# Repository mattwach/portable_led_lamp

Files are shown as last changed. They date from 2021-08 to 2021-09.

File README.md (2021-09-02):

# Portable LED Lamp

*The page https://www.instructables.com/Portable-LED-Lamp and [pdf file](Portable-LED-Lamp.pdf)
contain detailed build instructions, a prebuilt firmware (`led_lamp.hex`) file
and prerendered `.stl` files.  The rest of the instructions on this page give
some additional details on the project and to explain how to build your own firmware.*

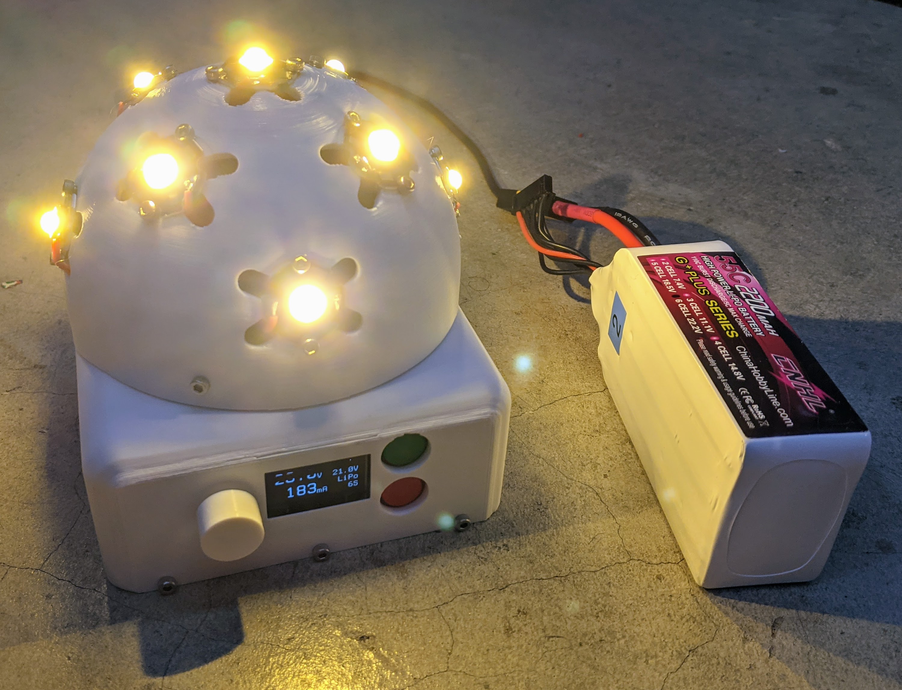
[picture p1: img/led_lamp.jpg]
Lamp Image


If you need light but don't have an outlet available, it's nice to have an
efficient light that can accept a wide variety of batteries.

This lamp can accept a wide range of voltages - between 6 and 30V. This allows
it to be **used with different batteries you may have lying around**, including
18650 packs, RC batteries, 12V lead acid, etc.

The unit is designed to be **very efficient** and puts out very little heat, even
at full power. A dimmer knob can be used to adjust the power consumption and
light output. When "off" the lamp consumes less than 40 uA of power in its
"sleep" state.

**Voltage and current are monitored on a small OLED display**. This allows you to
estimate battery life at a given light level and make adjustments as needed for
your situation.

The device has **automatic shutoff when the battery voltage gets too low**.

The device can autodetect the battery you are using with options for manual
override.

Before we get too far, a **disclaimer**:

**Using batteries carries a risk**. Making mistakes can lead to batteries catching
on fire. Sometimes batteries catch on fire even when everything is done
correctly due to unknown issues during manufacturing or shipping. It is
expected that you understand the risks associated with the battery you choose.
Even though the hardware and software in on this page have been tested, you
should not assume that your build and batteries will operate without problems.
I take no responsibility for issues you may encounter while following this
guide or using the provided software. Using a safety container for your battery
is recommended.

# Project Overview

This project contains:

  * Firmware in the `firmware/` directory.  This firmware is intended for the
    ATMega328p running at 3.3v and 8Mhz.  A 3.3V Arduino Pro Mini meets these specs
  * A [KiCad](https://www.kicad.org/) schematic and PCB layout in the
    `schematic/` directory
  * An [OpenSCAD](https://openscad.org/) 3D printable enclosure in the
    `3d_print/` directory.

# Schematics and Images

You'll want the free KiCAD tool to work on the schematics.  The images below are
screen captures from KiCAD for quick reference.

#### Master Board Schematic

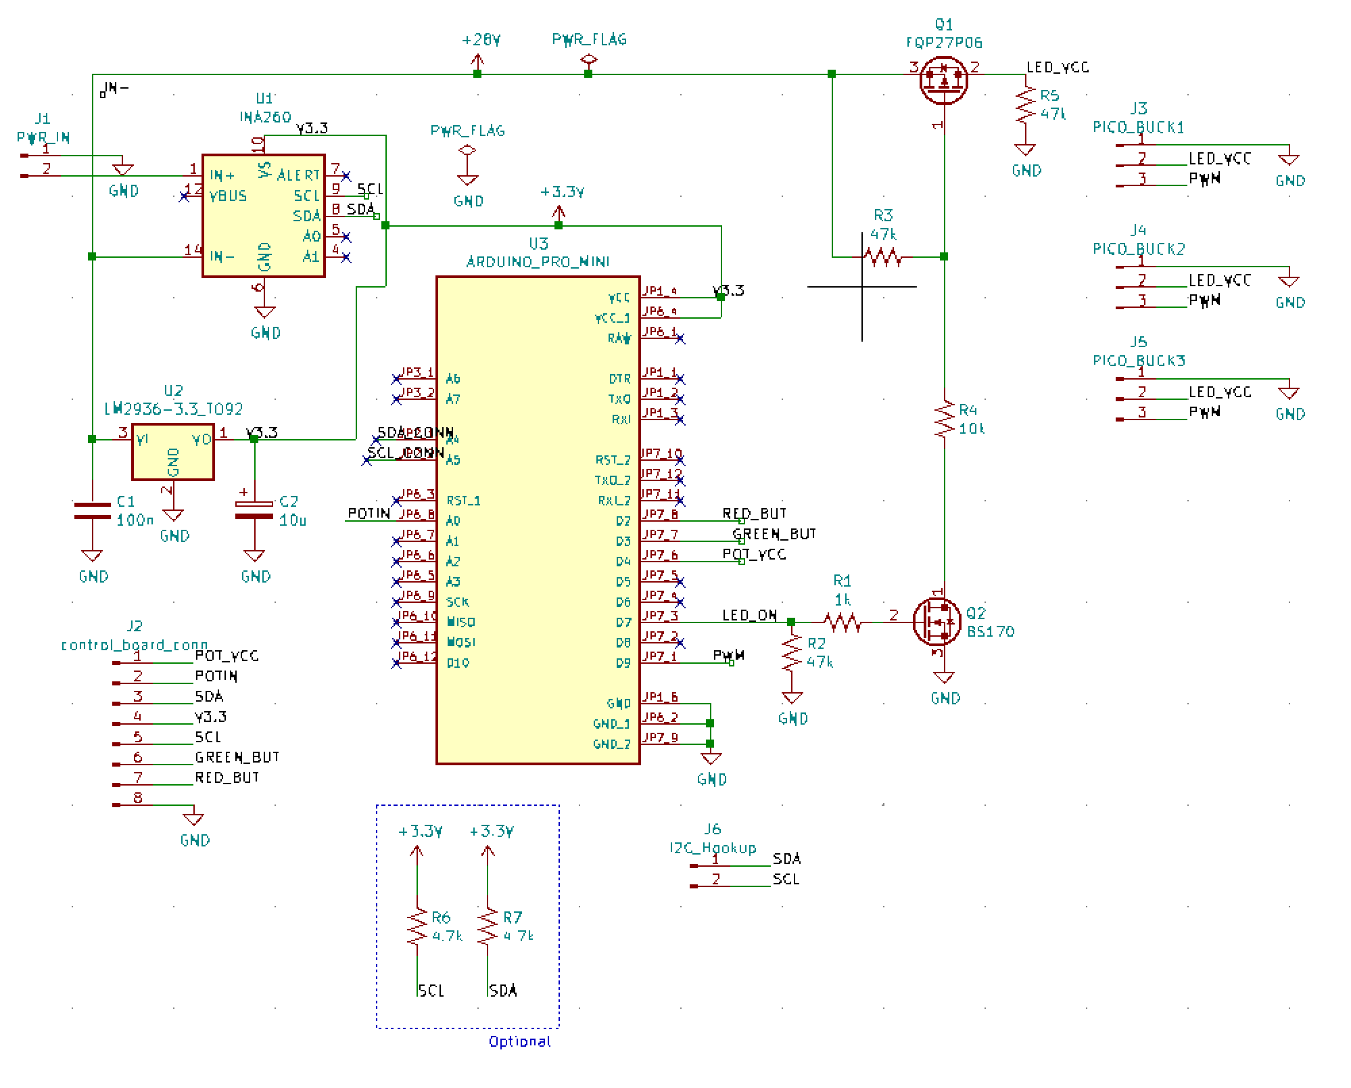
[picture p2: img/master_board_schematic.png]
Master Board Schematic


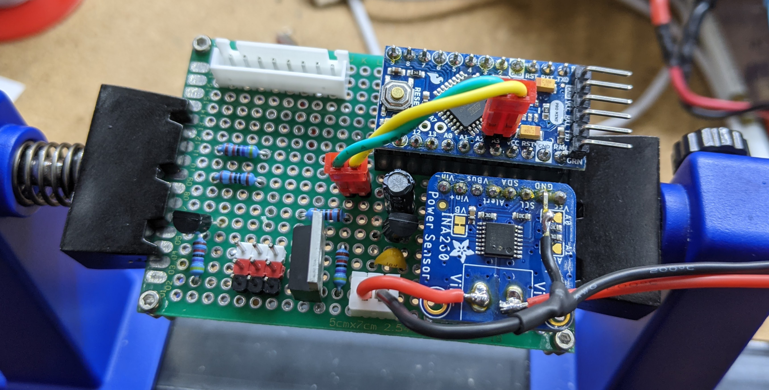
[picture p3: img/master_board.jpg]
Master Board Image


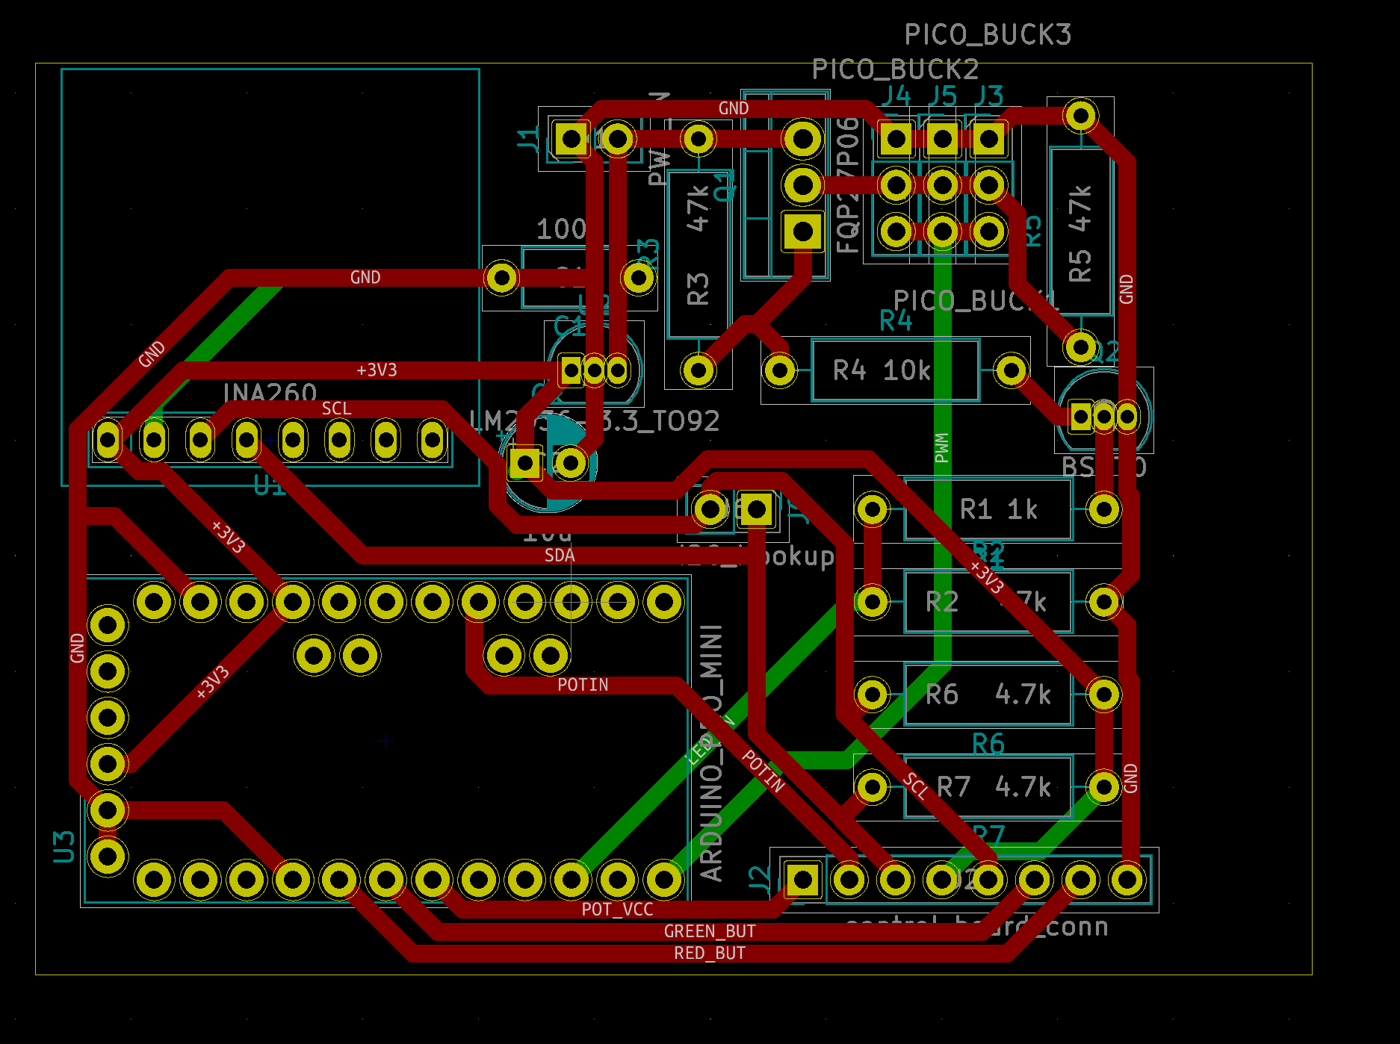
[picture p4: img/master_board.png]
Master PCB


#### Input Board Schematic

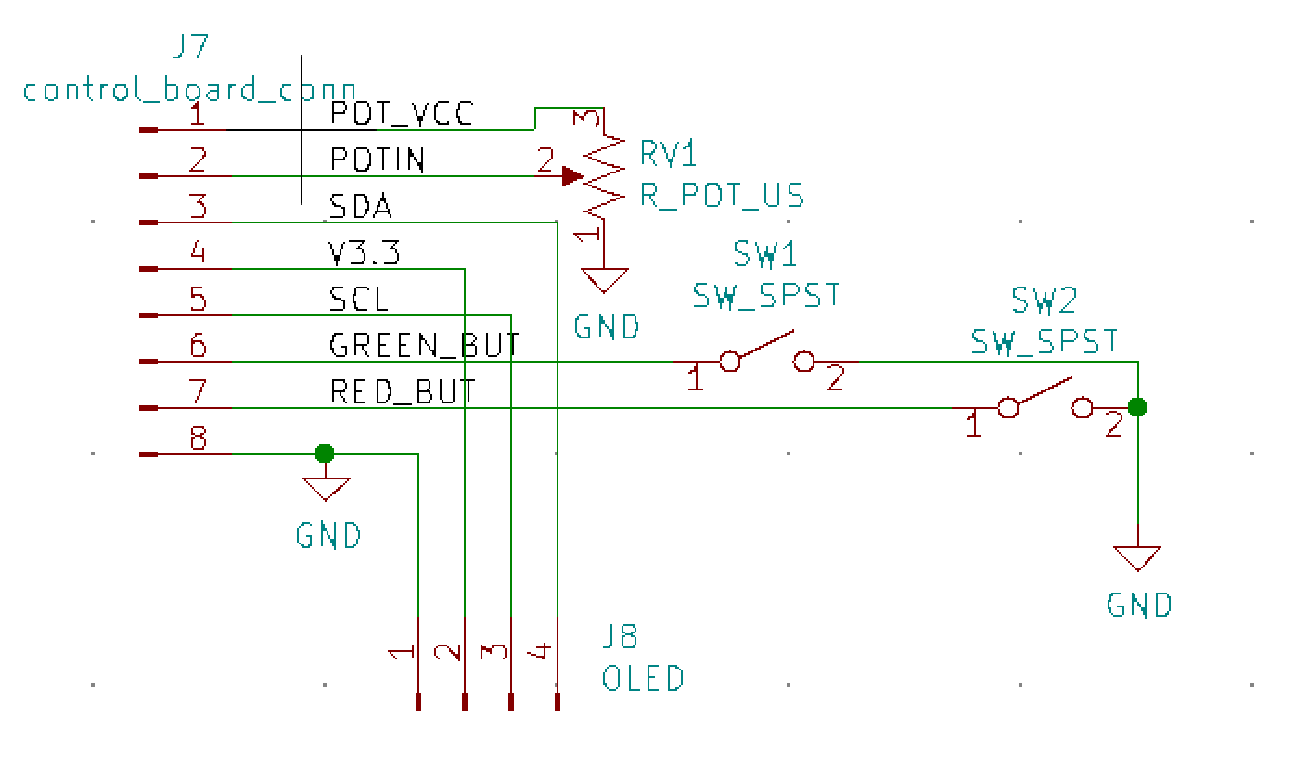
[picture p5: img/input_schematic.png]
Input Schematic


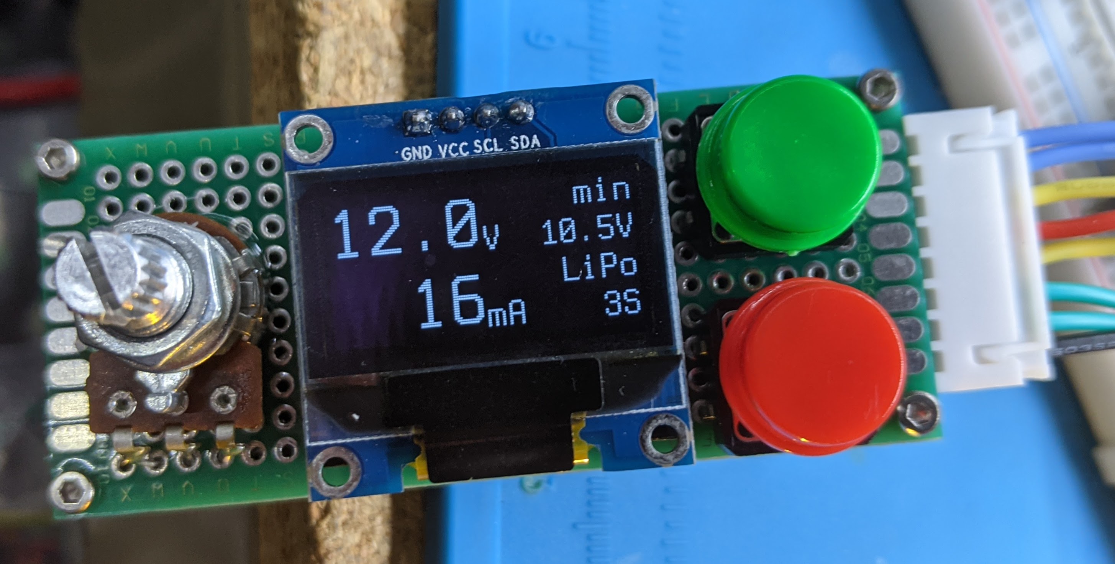
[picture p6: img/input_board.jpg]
Input Board


# Building the firmware

You will need the following commandline tools available.  All are free tools.
Getting them will vary depending on your operating system.

  * `avr-gcc`
  * `avr-objcopy`
  * `avrdude`

To build you run

    make

from the `firmware/` directory.  To upload to a ATMega328p (pro mini) you run

    make upload

Note that upload is currently not setup for windows, although it could be made
to work with a few tweaks to the relatively-simple `rules.mak` file.  The main
issue is likely to be incorrect `avrdude` parameters.  See the main `avrdude`
documentation for for more information.

# Enclosure (using OpenSCAD)

The file `3d_print/led_lamp.scad` contains the 3D models.

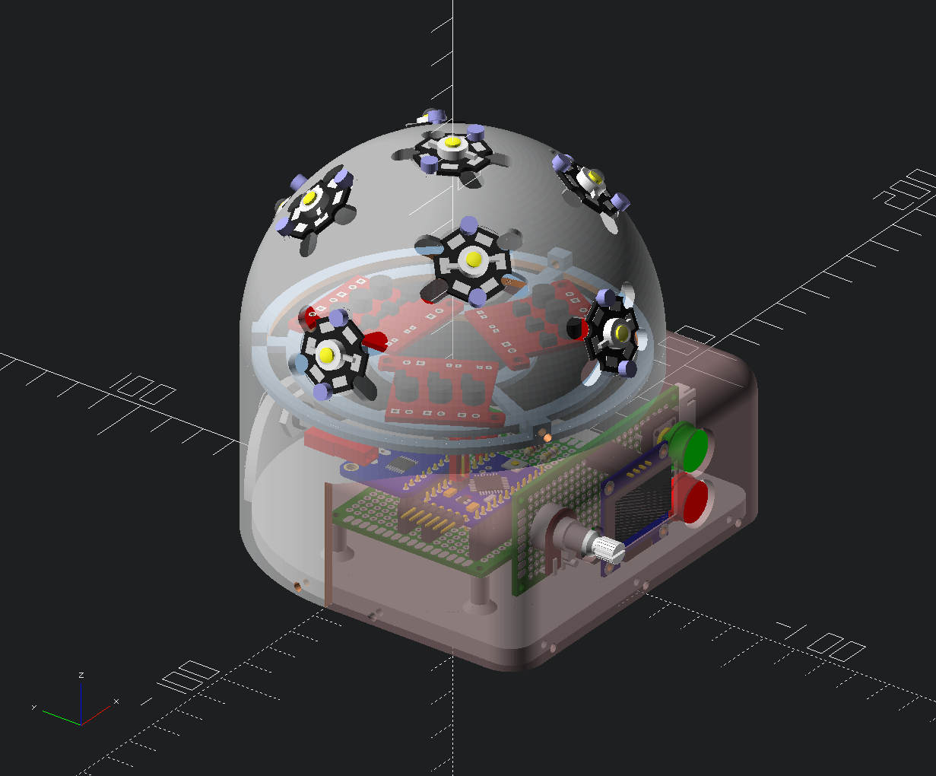
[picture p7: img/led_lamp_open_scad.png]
LED Lamp 3D Model


At the bottom of the file is a section:

    placed_master_pcb();
    placed_input_pcb();
    placed_picobuck_mount_plate(add_picobucks=true);
    placed_barrel_connector();
    lamp_base();
    placed_led_dome(show_leds=true, barrel_connector_cutout=true);
    input_holder();
    placed_dimmer_knob();

You can place a `*` character or comment out a line with a `//` to omit the
part.  You can also prefix a line with `!` to only show that part.  This is
useful for isolating a part for making a `.stl` model for printing.

# Design Notes

In have [design notes](DESIGN_NOTES.md) where I share test results for LED
efficiency, component power usage and other considerations.

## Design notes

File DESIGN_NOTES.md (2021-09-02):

# Design Notes

## Measuring LED Efficiency

The question here is what current are the LEDs the most efficient at?  Do you
get more light running 1 LED at 1W or 2 LEDs at 0.5W each?
[This website](https://tehnoblog.org/smd-led-chips-characteristics-size-power-efficiency/)
has some good information but did not cover the specific LED I purchased.  So I
decided to do some testing with a light meter.  Here is the setup:

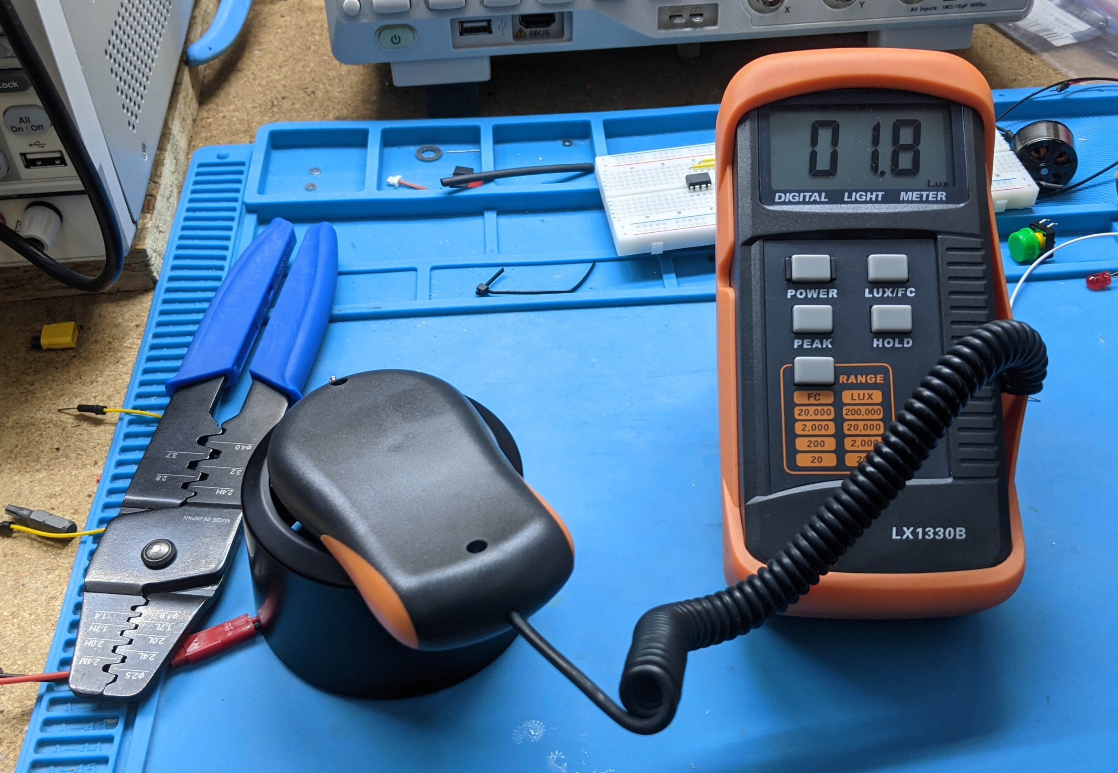
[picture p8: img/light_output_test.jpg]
Test Setup


Inside the black lens hood is an LED.  The device measures the Lux detected on
it's sensor.  I ran different currents through the LED, noting the voltage
and lux 
[recording the measurements this spreadsheet](https://docs.google.com/spreadsheets/d/1-tIt16MrtUSSaDjhF26bp0V8y1RnZGNZchjPFLyIPXU/edit?usp=sharing).
I ran 2 led's 2 times for a total of 4 measurements.  From the data, I created two graphs:

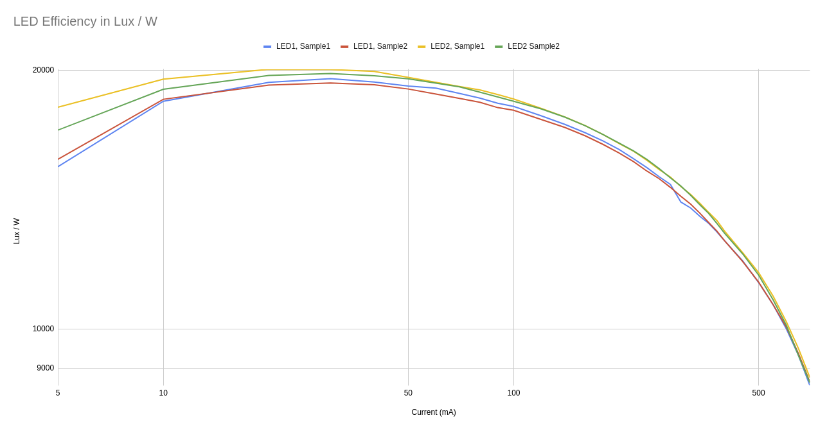
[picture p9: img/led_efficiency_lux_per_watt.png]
LED Efficiency


This graph shows Lux/Watt (efficiency) at a given current for all collected
samples.  It is showing that the LED is most efficient at ~20-50mA where
efficiency starts to drop off.  Note that the LED *is still getting brighter* as
current increases, but more energy is being *given off as heat* instead of light.
**Thus one can roughly conclude that using as many LEDs as possible is the most
efficient** as long as you are using at least 40mA per LED.

Here is another way to look at the data:

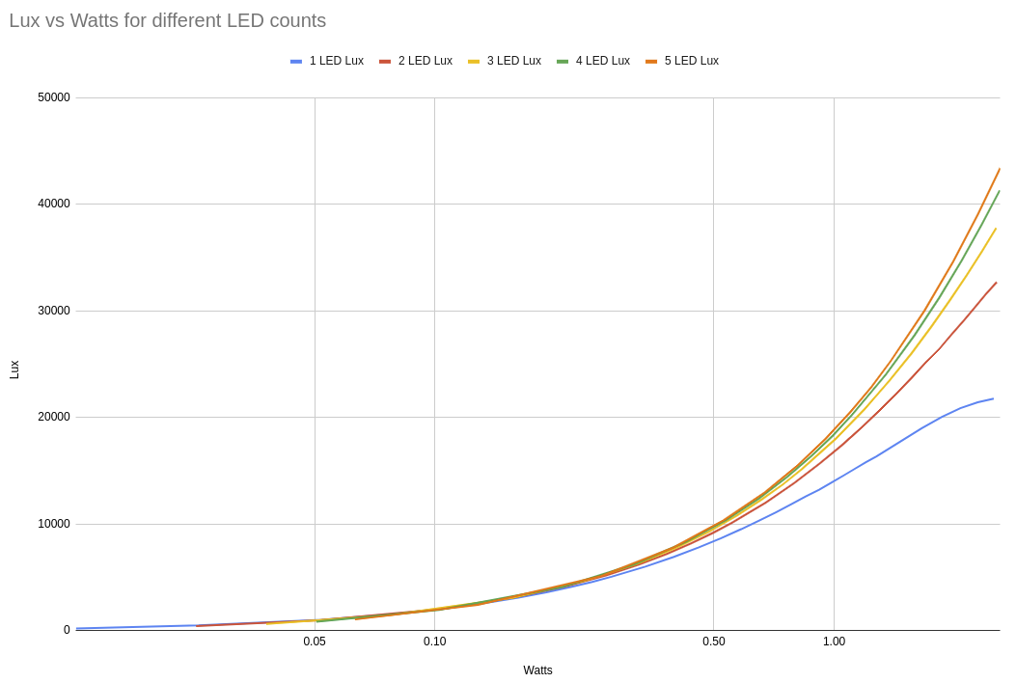
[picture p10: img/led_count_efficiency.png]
LED Count Efficiency


This case looks at choosing 1-5 LEDs and how much light you would get for a
given power budget.  From the graph, it looks like gains start around 0.5W and
become interesting above 1W.  Adding additional LED's has diminishing
returns, although still interesting at higher power budgets.

# OLED Power Consumption

To measure current, I used an ATTiny85 as the driver because it was a
convenient way to test at 3.3V (provided with a bench power supply).  Since I'm
only measuring current through the OLED, the device is irrelevant anyway.

The test toggles between the DISPLAYON and DISPLAYOFF I2C command every 4
seconds.  I wanted to see the current draw difference and get some confidence
as to the reliability of the commands (which I have not used before)

Here is the ON measurement:

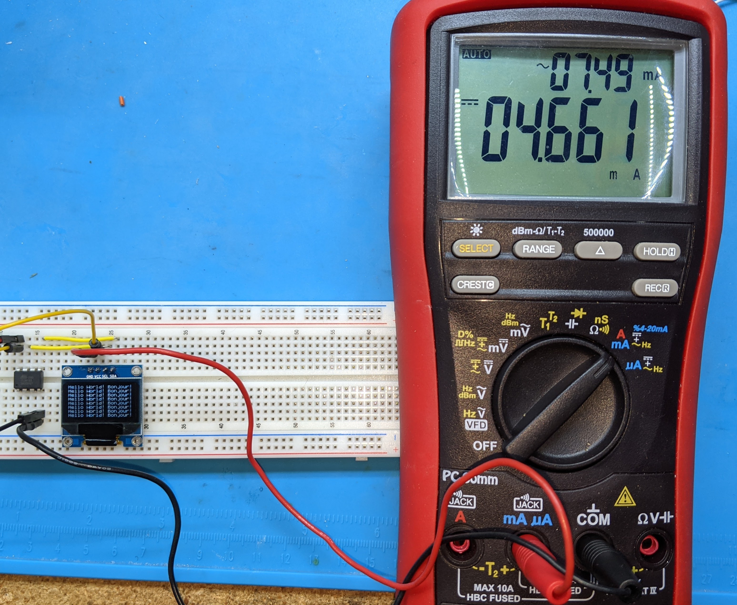
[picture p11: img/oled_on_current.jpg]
OLED On Current


4.4 mA (15 mW) is not bad but more load than I would prefer when in the
"battery is depleted" shutoff state.  4.4 mA over 24h would be 104 mAh (post
buck) which could be a problem for an already-depleted smaller 2S pack.

With the DISPLAYOFF command:

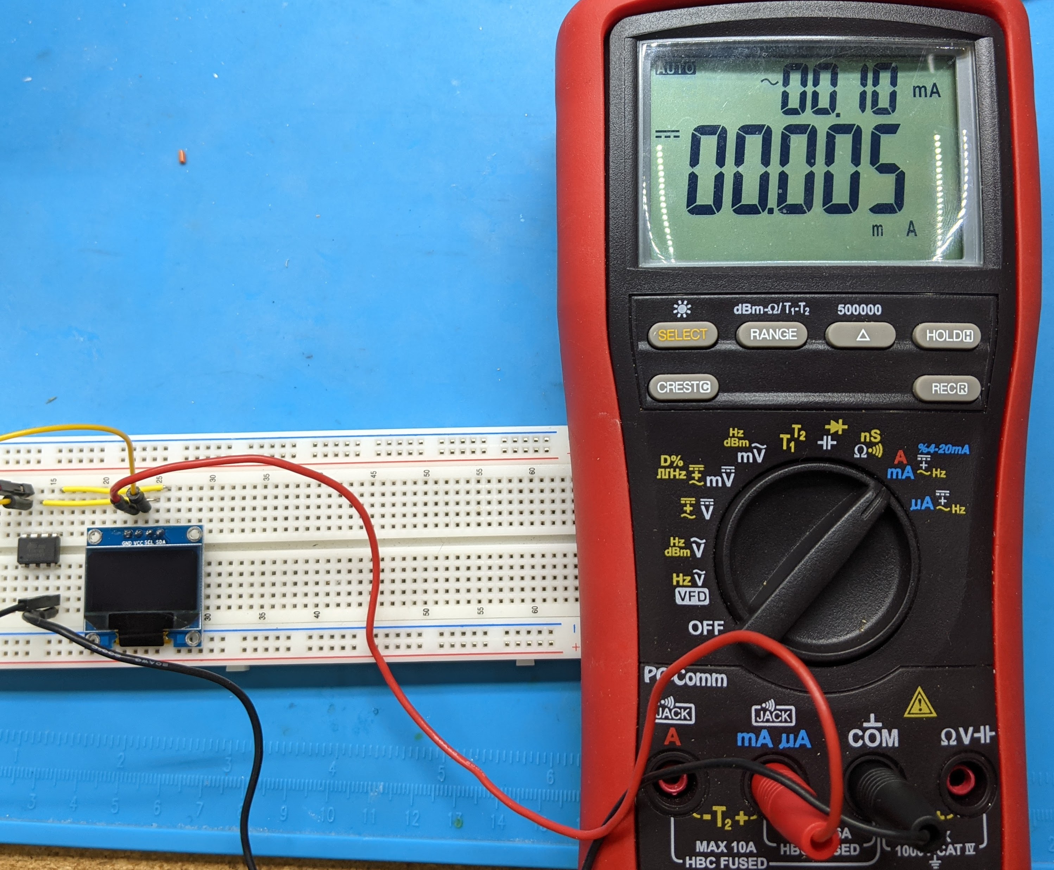
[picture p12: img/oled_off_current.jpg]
OLED Off Current


5 uA, pretty much a non-issue from the OLED, even if a small depleted pack is
left connected for a long time.

The tests also suggested that toggling between DISPLAYON and DISPLAYOFF will
work reliably.

# INA260 Testing

I setup the INA260 in an isolated test where I compared the reported value to a
multimeter measured value.  

For voltage, I found the INA260 to be very accurate.

For current, I found that the current read 2 mA low on both of my devices. By
simply adding 2mA to the result, I was able to get numbers within 1mA of the
multimeter across a 0-60mA range of values.  Good enough.

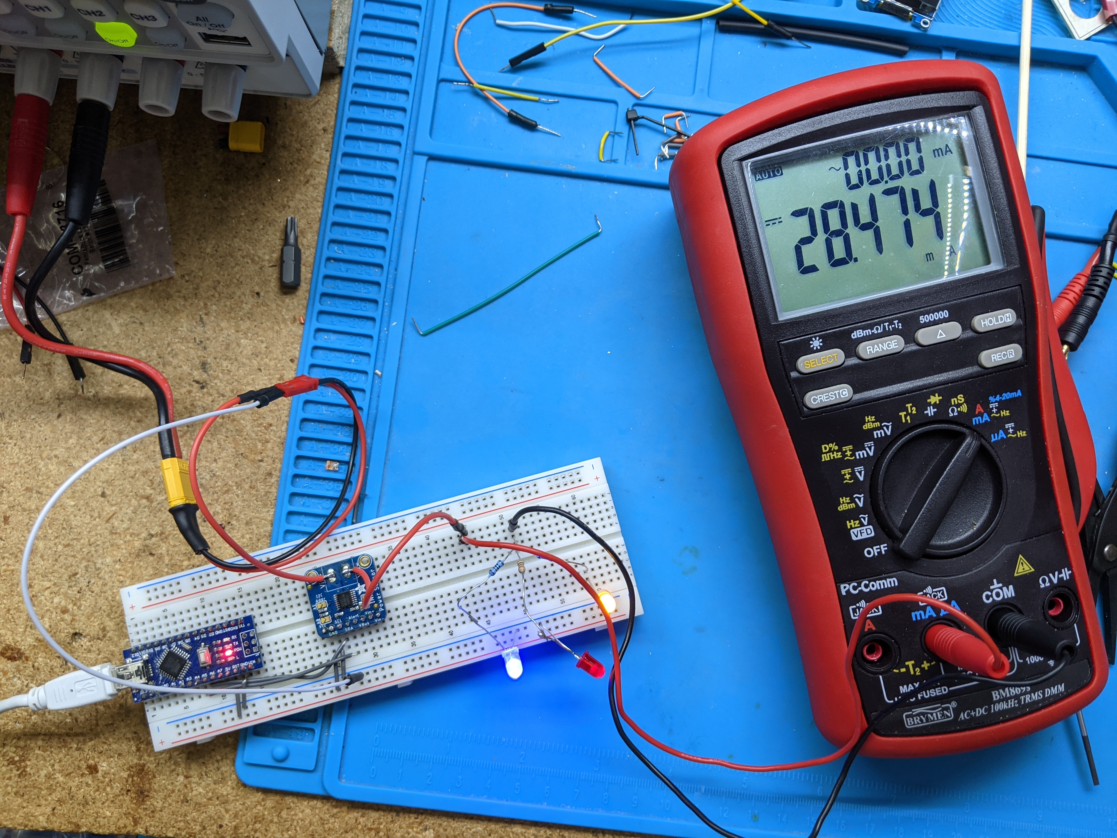
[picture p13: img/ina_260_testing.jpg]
INA260 testing


I also tested current draw into the INA260 in acive and sleep modes.  I measured
322 uA of draw in active mode and only 660 nA in sleep mode.

# PicoBuck Testing

I wanted to see if sending a grounded PWM signal to the PicoBucks would lower power
usage to acceptable levels.

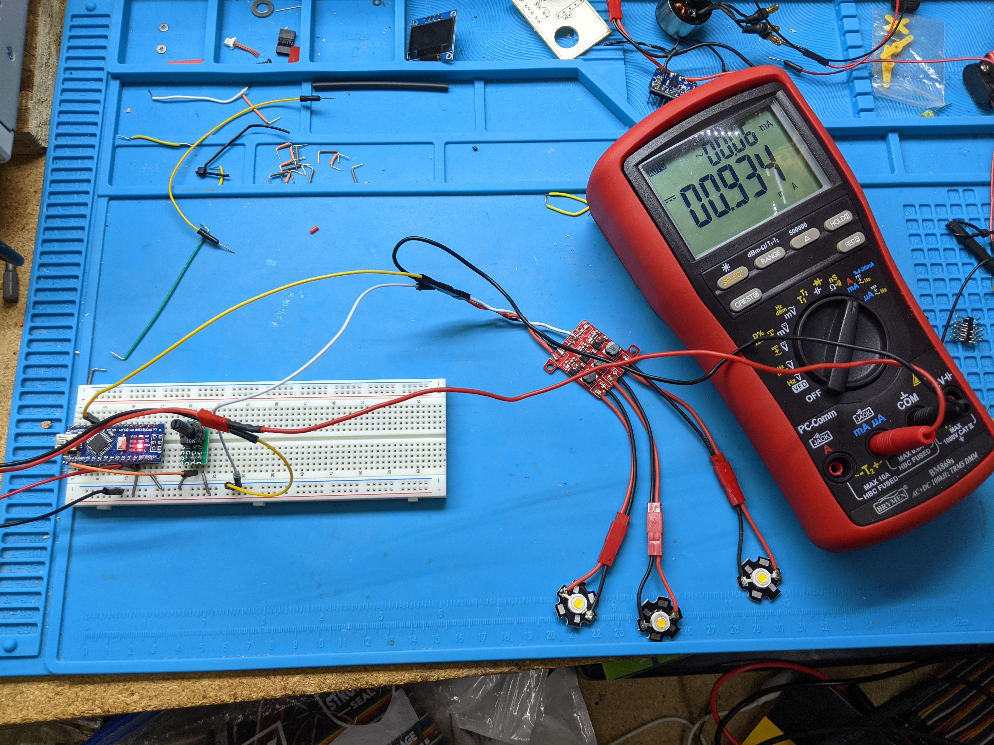
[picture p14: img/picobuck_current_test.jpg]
PicoBuck Current Test


Just a bit under 1mA.  Since I'm using 3 of these, the total "off" draw would
be just under 3 mA.  I think this is a bit too high to leave connected to a
depleted battery, thus I decided use a transistor to cut power to the PicoBucks
while the light is off.

# Pro Mini Sleep Current 

I took a current measurement of the device after removing the
built in 3.3V regulator and diode (as recommended by
[various low power guides](https://www.the-diy-life.com/making-an-ultra-low-power-arduino-pro/)),
and putting the device into low power (sleep) mode.  I measured just under 20 uA,
which is higher than the guides suggest, but low enough for my project.

# Switch Design

I decided to go with a high side PFET solution of the following design:

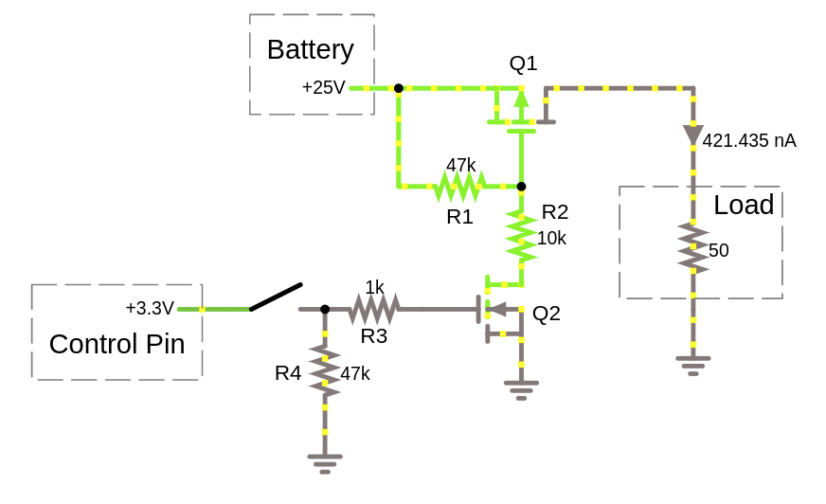
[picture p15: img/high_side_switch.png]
High Side Switch


Here are some notes on how the circuit works:

  * Q1 is the main component.  It is a Power P-Channel MOSFET.  I used the
    FQP27P06 but others could work.  As a PFET, it is "ON" when the gate voltage
    is pulled below the source.
  * R1 is a pullup resistor that turns off Q1 by default
  * R2 prevents the voltage from being pulled too low.  Every P-Channel MOSFET
    has a maximum rated Vgs that should not be exceeded and this rating will
    determine the correct ratio between R1 and R2.
  * Q2 pulls the gate of Q1 down.  Thus, when Q2 is on, Q1 is also on.  Q2 is
    needed to handle the voltage at the Q1 gate, which is too high to handle
    directly with a microcontroller.
  * R3 is used to dampen potential oscillations that can occur when switching
    Q2 on and off.
  * R4 pulls Q2 to ground by default, which means that the microcontroller does
    not need to actively drive that connection for the light to be off.  This
    provides stability while the microcontroller is starting up and is a good
    general default mode.

### N-Channel MOSFET?

Many designs go with an N-Channel MOSFET, which might require fewer components.
This "lowside" solution creates the concept of 2 independent grounds because
the PicoBuck ground would be on the high side of the MOSFET.  The PicoBuck
supports separate grounds for logic and power but now the total number of wires
to the PicoBucks is 4 (Power, Power Ground, PWM, PWM Ground) instead of 3,
something to consider if you want to modularize the design.

A bigger issue is that 3.3V doesn't fully saturate most N-Channel MOSFETs, which
will limit the current to some peak value that varies by MOSFET.  To Overcome
this, we would either need to switch to 5V logic (which uses more power), or
add an additional transistor to allow a higher Vgs (which negates the
simplicity).

### Darlington NPN?

This low side solution should work fine and would be a fairly simple circuit.
There will be a bit of power lost at the Vbe junction and current limiting
resistor when the circuit is on but it could be argued as acceptable.  A
reasonable alternative with the same "2 grounds" downside as the N-Channel
MOSFET.

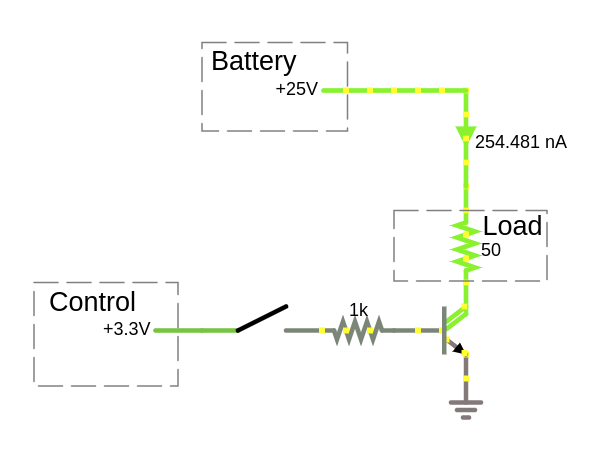
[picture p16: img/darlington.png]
Darlington Low Side


### Relay?

The main benefit of a relay is *potential* full isolation between logic and
power.  This is not needed or usable here, since the same battery powers the
logic and LEDs.  Downsides differ between mechanical and solid state.  For
mechanical, managing the coil is a downside.  Solid state could be fine but
check the datasheet specifications.

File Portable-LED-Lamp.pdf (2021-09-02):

instructables

Portable LED Lamp (http://www.instructables.com/Portable-LED-Lamp/)

by mattwach (http://www.instructables.com/member/mattwach/)

Note: this page focuses on building the lamp. If you want to customize the rmware, hack on the 3D models, or read about more design details,see the associated github project. (https://github.com/mattwach/portable_led_lamp)
If you need light but don't have an outlet available, it's nice to have an ecient light that can accept a wide variety of batteries.
The lamp can accept a wide range of voltages - between 6 and 30V. This allows it to be used with di

erent batteries
you may have lying around, including 18650 packs, RC batteries, 12V lead acid, etc.
The lamp is designed to be very ecient and puts out very little heat, even at full power. A dimmer knob can be used to adjust the power consumption and light output. When "o-" the lamp consumes less than 40 uA of power in its "sleep" state.
Voltage and current are monitored on a small OLED display. This allows you to estimate battery life at a given light level and make adjustments as needed for your situation.
The device has automatic shuto

when the battery voltage gets too low. The device can autodetect the battery you are using with options for manual override.
Before we get too far, a disclaimer:
Using batteries carries a risk. Making mistakes can lead to batteries catching on re. Sometimes batteries catch on re even when everything is done correctly due to unknown issues during manufacturing orshipping. It is expected that you understand the risks associated with the battery you choose. Even though the hardware and software in on this page have been tested, you should not assume that your build and batteries will operate without problems. Itake no responsibility for issues you may encounter while following this guide or using the provided software. Using a safety container (https://www.amazon.com/Lipo-Storage/s?k=Lipo+Storage) for your battery is recommended.

Supplies:
Needed Supplies
This is what I used. If you understand the design, you can swap out many of the parts below for alternatives.
1. 3.3V Arduino pro mini: (https://www.sparkfun.com/products/11114) $10 (or a low cost clone (https://www.ebay.com/itm/333324921249) $3)
2. 3 PicoBuck LED drivers: (https://www.sparkfun.com/products/13705) $48
3. 10 3W leds (solds in packs of 5): (https://www.sparkfun.com/products/13104) $16 (or cheaper ones on ebay (https://www.ebay.com/itm/122604065816) $5)
4. 128x64 I2C OLED (US shipping): (https://www.ebay.com/itm/382850692423) $6 (or CN shipping (https://www.ebay.com/itm/313626641218) $2)
5. 3.3V Regulator LM2936: (https://www.digikey.com/en/products/detail/texas-instruments/LM2936Z-3.3-NOPB/440974) $2
6. INA260 Voltage/Current monitor: (https://www.adafruit.com/product/4226) $10
7. 10k rotary potentiometer: (https://www.sparkfun.com/products/9939) $1
8. 2x tactile buttons: (https://www.sparkfun.com/products/15326) $1
9. 5.5mm jack for power: (https://www.amazon.com/ThreeBulls-Pieces-5-5mmx2-1mm-Female-Connector/dp/B01N8VV78D) $2
10. P-Channel power MOSFET. (https://www.sparkfun.com/products/10349) I used the FQP27P06 (https://www.sparkfun.com/products/10349) but many could work. It just has to have a Vdss > 30V
Portable LED Lamp: Page 1

and an Id > 2A ($1)
11. N-Channel MOSFET. (https://www.digikey.com/en/products/detail/onsemi/BS170/244280) I used the BS170 (https://www.digikey.com/en/products/detail/onsemi/BS170/244280) most but anything with a Vdss >30V will work. (< $1)
12. Resistors: I used 3x 47k, 1x 10k and 1x 1k. Most of these values are not critical, ballpark will do. The one exception is the 1:5 ratio between the 47k and 10k should be similar.
13. PCB boards. I used a 30x70 and 50x70 prototype board (https://www.amazon.com/ELEGOO-Prototype-Soldering-Compatible-Arduino/dp/B072Z7Y19F). If you want to send the design to a fab, see the github ?les. (https://github.com/mattwach/portable_led_lamp)
14. M2 (https://www.amazon.com/Hilitchi-250-Piece-Stainless-Socket-Assortment/dp/B01N1WDUK0) and M2.5 (https://www.amazon.com/DYWISHKEY-Pieces-Stainless-Socket-Washers/dp/B082XPZV1V) bolts if you choose to use the 3D printed housing.
15. Some hookup wire. I think 22 gauge silicone wire (https://www.amazon.com/BNTECHGO-Flexible-Conductor-Resistant-Extension/dp/B077XBWX8V) is a good ?t but you can use what you have.
16. Optional: Connector between input PCB and main PCB. I went with 8 pin JST XH (https://www.amazon.com/Connector-pre-crimped-Housing-Adapter-Compatible/dp/B08G18PWQ6) connectors but many di-erent options can be used.
17. Optional: Some female pin headers (https://www.amazon.com/Glarks-Straight-Connector-Assortment-Prototype/dp/B076GZXW3Z) will allow you to plug and unplug the OLED, Power Monitor and Arduino. This can help with troubleshooting and protects the parts when soldering.

Price Range: $60 - $150, depending on where you get components, optional parts, shipping, etc.
Needed Tools
1. A 3.3VFTDI programmer. (https://www.sparkfun.com/products/9873) The linked one is $15 but there are many cheap alternatives.
2. A soldering iron and solder
3. Hex wrenches for assembly.
4. Optional: an ESD wrist strap (https://www.amazon.com/Corpco-Anti-Static-wrist-strap-removable/dp/B01D0O7M4E) is recommended when handling the MOSFETs. (https://e2e.ti.com/blogs_/b/powerhouse/posts/what-type-of-esd-protection-does-your-mosfet-include)
5. Optional: a breadboard will be useful for incremental validation.

This project also includes .stl ?les for a 3D printed enclosure. You can print it yourself, send the ?les to a service, or DIY your own case solution.
Needed Software
1. AVRDude (https://www.nongnu.org/avrdude/) for uploading ?rmware to the pro mini (free).
2. Optional: AVR GCC tools (https://www.google.com/search?q=avr+gcc+compiler) if you want to hack on the ?rmware or write your own. (free)
3. Optional: OpenSCAD (https://openscad.org/) if you want to hack on the 3D model ?les. (free)

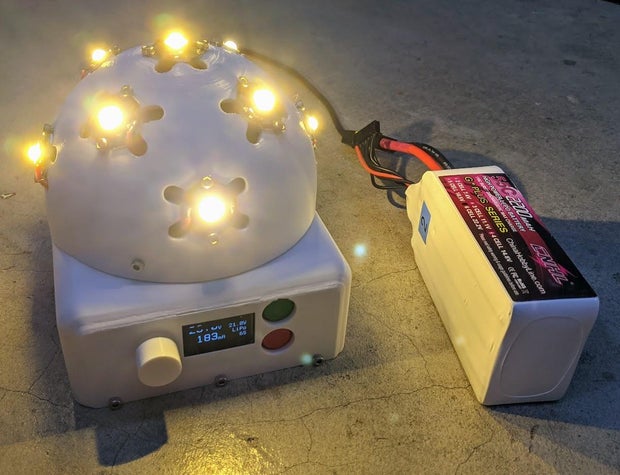
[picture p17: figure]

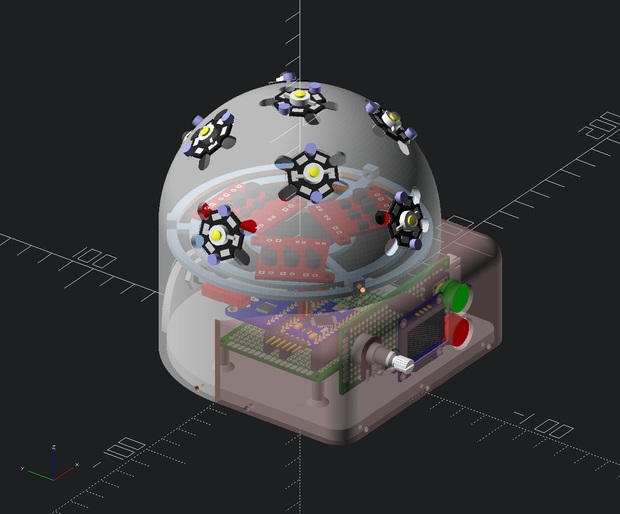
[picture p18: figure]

Step 1: Main Schematic Overview

Let's start with an overview of where we are headed. The schematic shows the ?nal circuit with everything connected. If this information looks overwhelming, feel free to skip it as we will be walking through the design in the upcoming steps:
Power comes in at the top left on J1, Pin 2. It feeds directly into the V+ port of an INA260 power meter. The power Iows through the V- port of the INA260. The INA260 will measure current that passes through V+ and V- and the voltage between V+ and GND
The V- of the INA260 connects to 2 devices
One is the LM2936 voltage regulator on the left (U2). This regulator drops the voltage down to 3.3V which is needed by the Arduino pro mini, the INA260 and the OLED. Although the pro mini has a built in 3.3V regulator, this built in regulator can not handle the 30V maximum rating on V-. The pro mini regulator also has a higher "quiescent current" which means that it is less power-ecient than the LM2936.
The other device connected to V- is a PFET (Q1). This is used to cut power to all to the

PicoBuck LED drivers. The 47k pull resistor (R3) pulls the gate to V- by default meaning that the PFET is o- by default.
The resistors and Q2 (NFET) are needed to switch the PFET on. The pro mini can not turn on the PFET directly because the voltage at the PFET gate is too high, thus an NFET (Q2) is used as a middle-man. The resistors R3 and R4 are used to keep the Vgs speci?cation of the PFET in range. The R2 resistor keeps Q2 o- by default. To turn on Q2, the arduino pro mini must drive D7 high. The R1 resistor consumes potential oscillations that can develop when switching Q2 on and o-.

Back to Q1, the PFET either blocks (nearly all) current or allows (nearly all) current, depending on it's state. The receivers of this current are 3 PicoBuck LED drivers, which are used to drive 9 3W LEDs.
Let's focus on the pro mini's interface pins
A4 (SDA), A5 (SCL): These are used to talk to both the INA260 and OLED via I2C. I2C is a bus architecture meaning that A4 connects to SDA of both the INA260 and OLED at the same time. Same for SCL.
A0: This connects to the center leg of a potentiometer for dimming the LEDs.
D4: This connects to the voltage (right) leg of the potentiometer. You could hook this leg directly to the 3.3V supply, but then the potentiometer would burn power even when the light is o-. By using D4, the pro mini can cut the power to the potentiometer when the unit is o-, saving 330 uA of current draw.
D2: This connects to the "green" push button. The other side of the button is connected to GND. This con?guration is called "open drain". Basically a pullup resistor internal to the pro mini keeps D2 high at 3.3V but this voltage can easily be pulled to ground by something like a button - which the pro mini will detect as a button press.
D3: Same idea as D2 but for the red button
D7: The arduino drives this pin to 3.3V to turn on Q2, which in turn turns on Q1, which turns on the LEDs. To turn o- Q2, we have the choice or driving D7 to GND or re-con?guring it as an input (Hi-Z) and letting R2 pull the gate to ground. The ?rmware takes the later choice. D9: This pins sends out a PWM signal. It tells the PicoBucks how much to dim the LEDs. The ?rmware makes this decision by considering the state of the lamp (is it on? is the voltage ok?) and by reading the potentiometer value
3.3V VCC, GND: Needed to power the chip

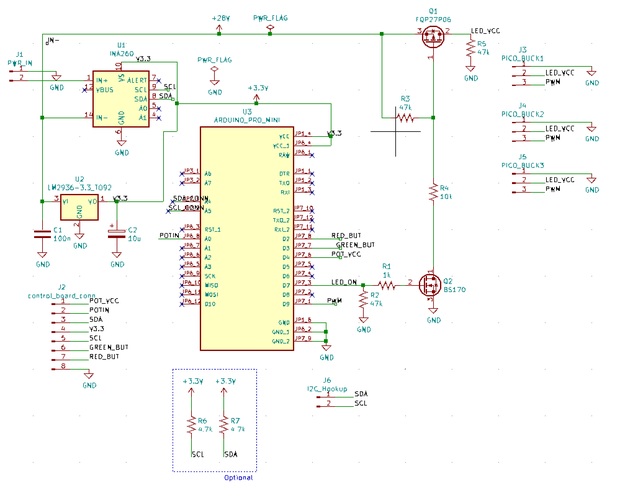
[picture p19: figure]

Step 2: Input Schematic Overview

The input PCB is wired on a separate board and connected via an interface cable to the main board. You don't have to use an interface cable if you are making your own case and want everything on one board.
Every component on this board was described in the previous step. If it's not clear what is going on, the upcoming breadboard examples should help.

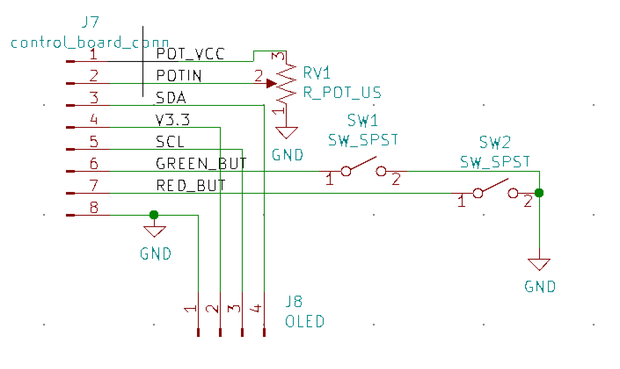
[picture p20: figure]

Step 3: Initial OLED Hookup and Firmware Test

Note: Consider all of the breadboard steps optional exercise for fun, education and part veriDcation. If you want to skip ahead to the Dnal build, feel free (and good luck).
For this step, we are just going connect the Arduino Pro mini to the OLED and upload ?rmware to the pro mini.
I recommend using a breadboard for this step.
1. Add the pro mini and OLED to the breadboard
2. The wiring to the OLED is
1. Pro Mini GND → OLED GND
2. Pro Mini VCC → OLED VCC
3. Pro Mini A4 → OLED SDA
4. Pro Mini A5 → OLED SCL
3. Now attach your 3.3V FTDI programmer to the Arduino Pro Mini Interface pins as shown in the photo and connect the USB cable to your PC

Now you need to upload the led_lamp.hex ?rmware ?le (link is below). This requires avrdude to be installed on your computer.
The command I used was:

<strong>avrdude -Cavrdude.txt -v -patmega328p -carduino -P/dev/ttyUSB0 -b57600 -D -Uflash:w:led_lamp.hex:i</strong>

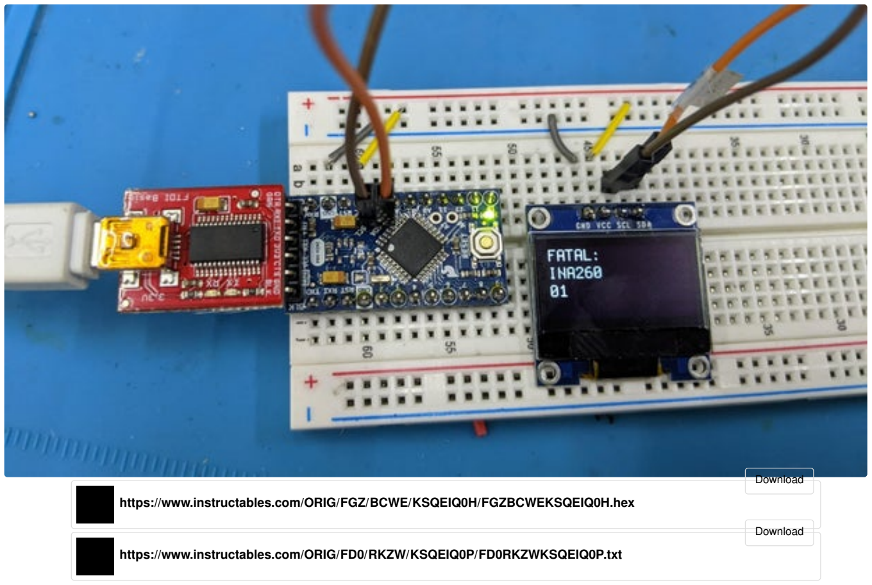
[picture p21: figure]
https://www.instructables.com/ORIG/FGZ/BCWE/KSQEIQ0H/FGZBCWEKSQEIQ0H.hex; Download; https://www.instructables.com/ORIG/FD0/RKZW/KSQEIQ0P/FD0RKZWKSQEIQ0P.txt

Step 4: INA260 Current Monitor Setup

I tested this in Arch Linux and Debian Linux but avrdude works on Mac and Windows too - you will need to adjust (or omit) the -P setting to correctly point to your serial device. Here are some avrdude docs (https://www.ladyada.net/learn/avr/avrdude.html) that might help with windows or mac.
You should see the error "FATAL: INA260 01". Although an error is being reported,things are going wellif you see this message (as we have not added the INA260 yet).

The INA260 current monitor is used to measure the voltage and current of the LED.
For now, we can just connect it onto the breadboard (the red wires in the photo are not connected to anything)
1. Connect Pro Mini GND → INA260 GND
2. Connect Pro Mini VCC → INA260 VCC
3. Connect Pro Mini A4 (SDA) → INA260 SDA
4. Connect Pro Mini A5 (SCL) → INA260 SDL

You will notice that all of the connections above are also connected to the OLED which is ?ne.
Power up the unit again and you should see it asking what type of battery you have as well as telling you you have zero volts.

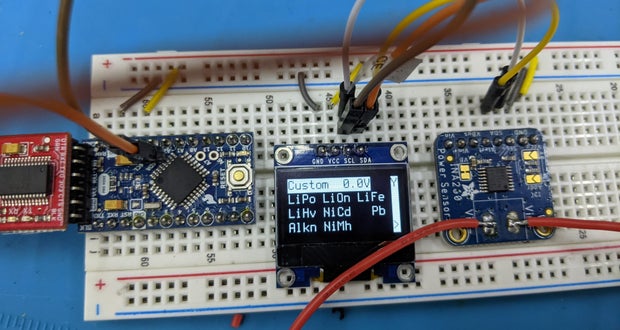
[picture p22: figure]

Step 5: Adding the Voltage Regulator

So far, the 3.3V has been provided by the FTDI programming board. For this step, we will install the voltage regulator so that we can run o- arbitrary (e.g. 6-30V) input power. That allows us to see the INA260 working now and allows us to power real LEDs later.
Wiring errors here can burn up parts. One way to avoid this it to use a regulated power supply and set the maximum current low (20 mA should be enough for now). Another way is to put a small fuse in series with your battery. A third way is to verify that the 3.3V regulator is working as expected before connecting anything to it.
The basic wiring Iow is as follows:
1. Battery + → V+ on the INA260
2. Battery - → GND
3. INA260 V- → Regulator Vin
4. Regulator Vout → 3.3V rail (which the pro mini, OLED and INA260 are all connected to)
5. Regulator GND → GND
6. Put the capacitors on the regulator as described by the datasheet.
1. The LM2936 datasheet (https://www.ti.com/lit/ds/symlink/lm2936.pdf) calls for Vin → 100nF → GND and Vout → 10uF → GND
2. . I have con?rmed with an oscilloscope that not using caps as suggested leads to unstable regulation with this part.

Your reward for getting everything correct is that the ?rmware will now show your voltage on startup. We still have no way to communicate with the unit but that will soon change.

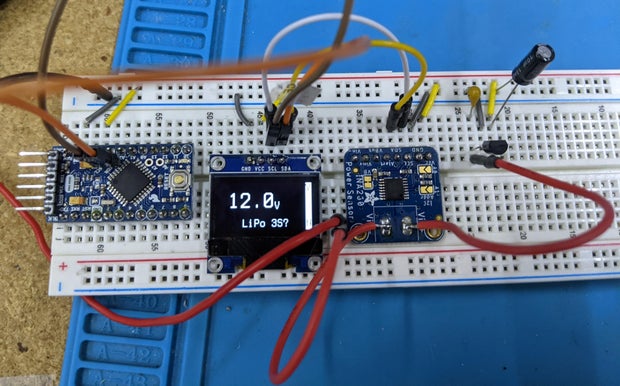
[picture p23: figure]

Step 6: Add Buttons and the Potentiometer

Here we add buttons and the potentiometer to the breadboard. In the next step, we build an input board. If you don't have good components for the breadboard, you can skip to the next step.
The buttons and potentiometer I used in this step are not the ones I'm using in the ?nal design, just some from the parts box. Wiring is as follows:
Pro Mini D2 → Red button (left side) Red button (right side) → GND
Pro Mini D3 → Green button (left side) Green button (right side) → GND Potentiometer (left pin) → GND
Pro Mini A0 → Potentiometer (center pin) Pro Mini D4 → Potentiometer (right pin)

Now you can control the unit. The unit will think it's controlling a real LED at this point and the controls will respond like the ?nal design. In this design green is on, red is o- and the potentiometer controls brightness.
Here I added a temporary LED and resistor (1k) between D9 and GND. D9 is the PWM output that will allow us to dim our LEDs. In the ?nal design, D9 is just a signal to the Picobuck converters but here I use it to drive power through a small led for a direct demonstration. The oscilliscope signal shows the output of D9. As you turn the potentiometer to the right, the duty cycle of the square wave changes and is at 3.3V for more of each period. The buttons also change the state of the unit and turns the PWM on and o-.

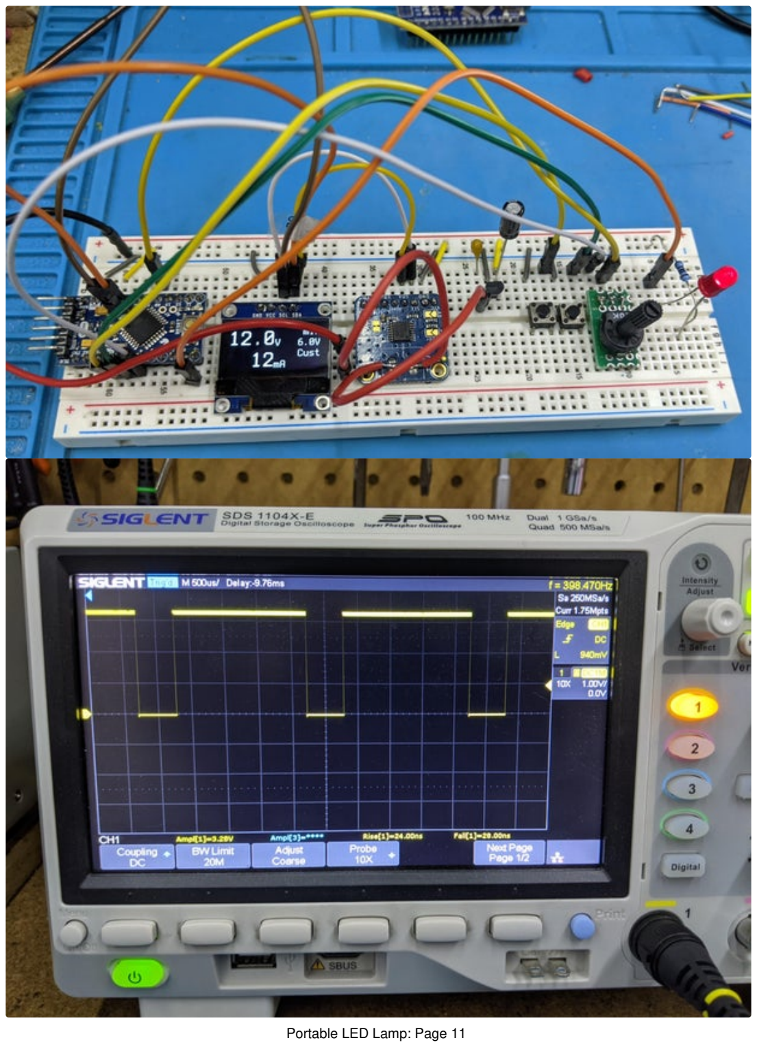
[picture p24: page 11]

Step 7: Build the Input Board

See the schematic in step 2 for the wiring. I used a 70x30mm prototype PCB for this. If you want the input board to ?t nicely into the 3D print, pay close attention to the part placement. I suggest counting the PCB holes as a reference.
I glued the potentiometer to the board with epoxy.
To connect the input board to the main board (and breadboard), I went with a male 8 pin JST XH connector (2.54 mm pin pitch). You can go with whatever connector you want, including directly soldering on the wires.

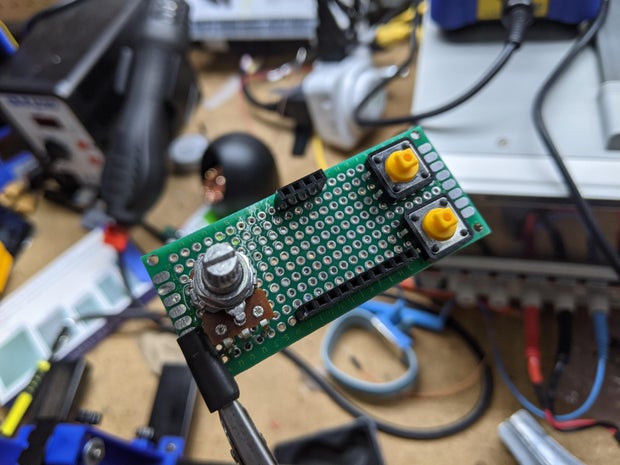
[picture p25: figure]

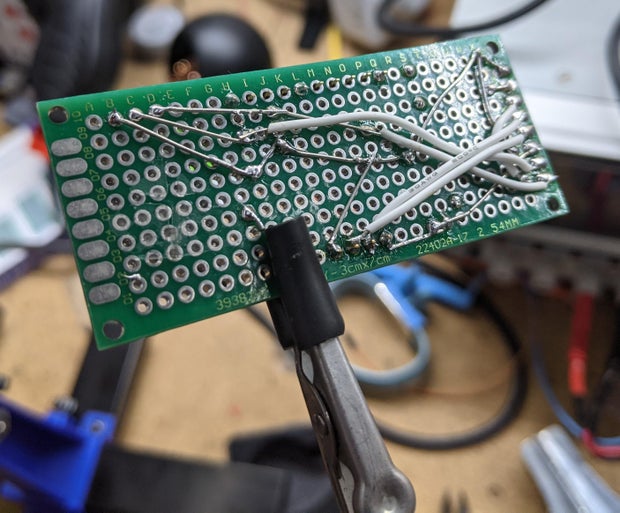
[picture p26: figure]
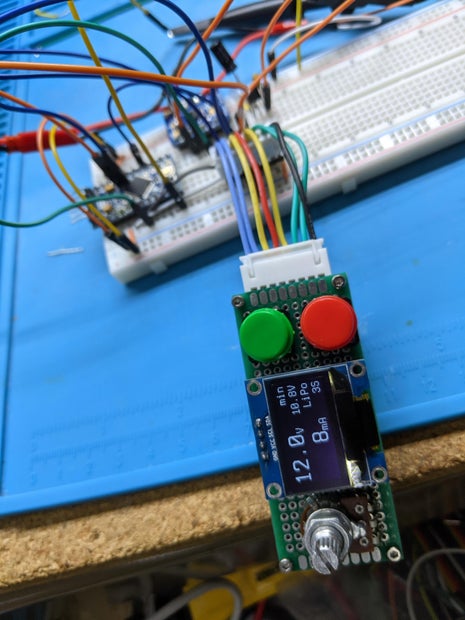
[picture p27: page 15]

Step 8: Prepare a PicoBuck and 3 LEDs

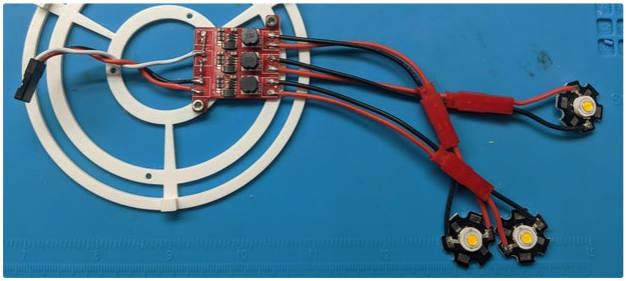
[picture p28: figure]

Step 9: Wire Up and Test the PFET Switch

The photo shows the PicoBuck on the 3D printed assembly but you do not need the assembly yet.
For the PicoBuck, you can short all of the PWM inputs together as shown in the photo. You can also short together the signal and LED GND on the board (assuming you go with the high-side PFET switch used in this guide. If you opt for a "low side" switch, you would not short them).
I used JST connections between the LEDs and picobuck. It's probably not necessary. As long as your wires are 3.5-4 inches (90-100mm), you should be able to use the 3D printed dome without the connectors.

The schematic is in step 1. You basically need a power PFET, any NFET and 4 resistors. The 47k pulldown from the PFET to the PicoBuck is optional - it will allow the voltage to drop to zero when the PFET is o-.
The photo shows a FemToBuck instead of a PicoBuck. They can be used interchangeably.
Note: you also have the option of omitting the PFET/NFET switch, plugging V- from the INA260 directly into the PicoBuck power input. Things will still work as the "o-" position of the ?rmware also Iatlines the PWM signal at D9. The downside is that each PicoBuck uses about 1 mA in this con?guration for a total waste of 3mA, even when the unit appears o-. Using the PFET avoids this 3 mA parasitic drain.

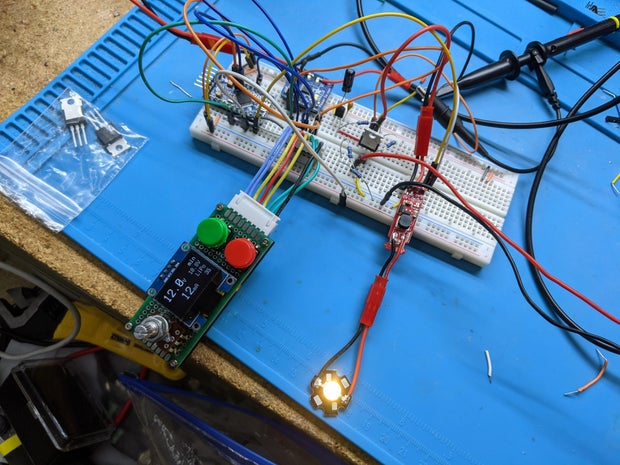
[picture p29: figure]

Step 10: Build Master PCB

Now we transfer the breadboard circuit to a PCB. I used a 50x70mm PCB which is also what the 3D print is designed to use. I used kicad (https://www.kicad.org/) to help layout the components (?les here) (https://github.com/mattwach/portable_led_lamp) before wiring up the board. Note that the kicad schematic contains 4.7k pullup resistors for SDA and SCL. The INA260 and OLED already have pullup resistors onboard and the 4.7k pullups were never needed in testing, so I did not include them in my actual wiring.

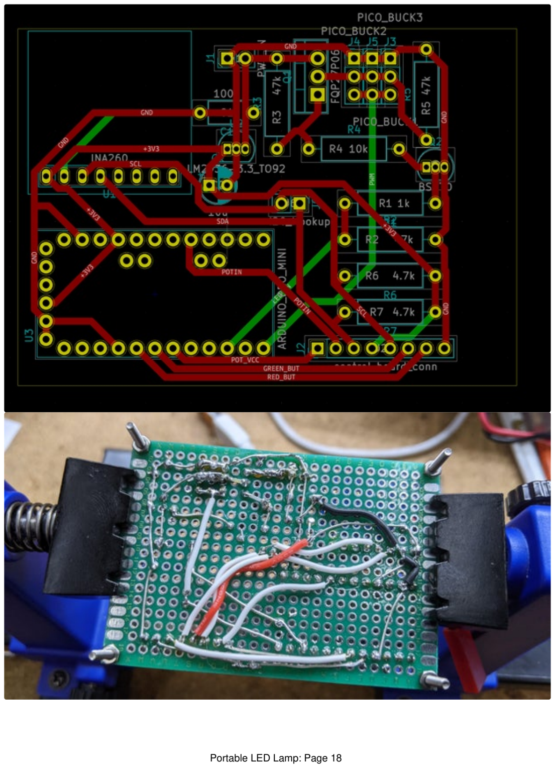
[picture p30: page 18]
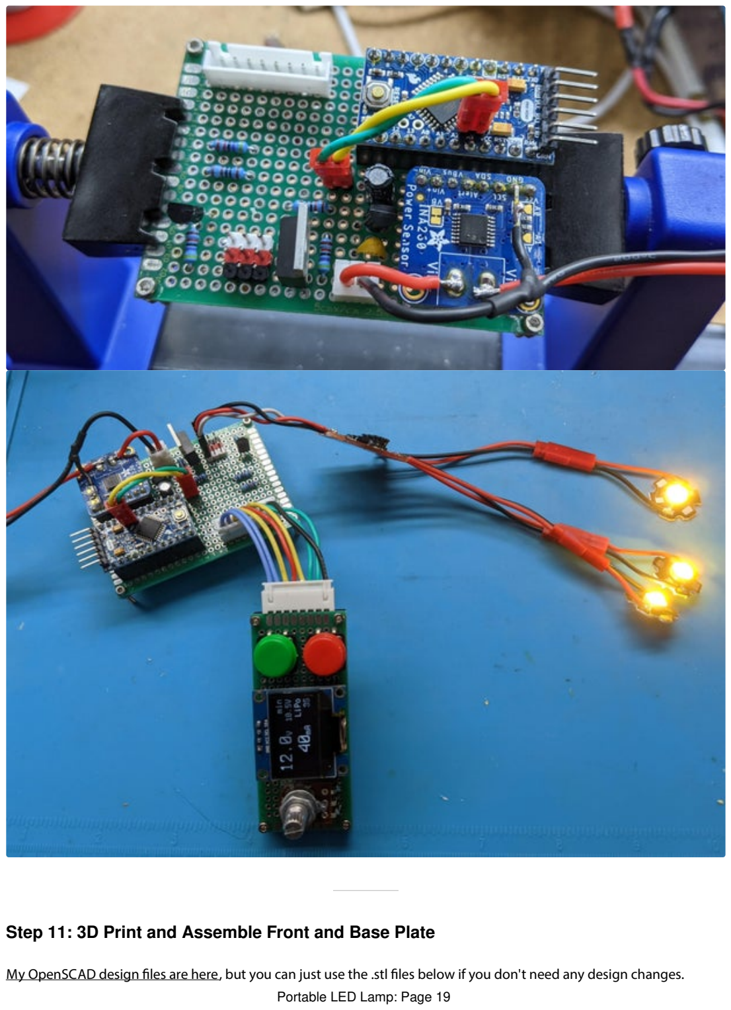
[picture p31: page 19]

Step 11: 3D Print and Assemble Front and Base Plate

My OpenSCAD design ?les are here, (https://github.com/mattwach/portable_led_lamp) but you can just use the .stl ?les below if you don't need any design changes.

I used 0.15mm layer height in PLA. A 0.2mm height could also be used. PETG or other ?laments can be used in place of PLA. I printed the front face with supports for the curved surfaces - they might not be necessary.
There is a hex nut hole in the middle of the base. It can be ?tted with a 1/4-20 hex nut which will then allow the lamp to be attached to a standard tripod mount.
The front attaches to the base with M2.5 bolts. Anything between 6mm and 16mm should work. Be careful not to over-tighten the bolts or they will strip plastic.



https://www.instructables.com/ORIG/FBI/O692/KST8YWEX/FBIO692KST8YWEX.stl; View in 3D; Download; https://www.instructables.com/ORIG/FXQ/J1PD/KST8YWEY/FXQJ1PDKST8YWEY.stl

Step 12: 3D Print the Picobuck Mount and Attach the Picobucks

The PicoBuck drivers attach with M2.5 bolts. Anything over 6mm should be ok. The bolts do not need to be very tight and tightening them too much will strip plastic.



Step 13: Print Led Dome and Do Final Pretest https://www.instructables.com/ORIG/FA2/G5UJ/KST8YX16/FA2G5UJKST8YX16.stl (https://content.instructables.com/ORIG/FA2/G5UJ/KST8YX16/FA2G5UJKST8YX16.stl)

View in 3D Download (https://content.instructables.com/ORIG/FA2/G5UJ/KST8YX16/FA2G5UJKST8YX16.stl)

I used both a raft and support for this print - the raft is helpful because the top of the dome has small details which do not make for a good ?rst layer.
Before continuing with ?nal assembly, plug the PicoBucks into the PWM ports on the main board and assert that the light works as expected



Step 14: Final Assembly and Notes https://www.instructables.com/ORIG/F20/A32K/KT37UYTM/F20A32KKT37UYTM.stl (https://content.instructables.com/ORIG/F20/A32K/KT37UYTM/F20A32KKT37UYTM.stl)

View in 3D Download (https://content.instructables.com/ORIG/F20/A32K/KT37UYTM/F20A32KKT37UYTM.stl)

Attach the dome to the base with M2.5 bolts that are between 6mm and 16mm long. Attached below is a 3D printable dimmer knob that you can push onto the potentiometer to ?nalize the build.
Some notes for future designs:
The unit could be modularized into two components. One provides power, PWM and monitoring. The other is just the needed buck (or boost) converters and LEDs. This would allow for di-erent LED modules, such as a Iat/directional one. Or LEDs with di-erent color temperatures
Other sensors could be added, such as a photo resistor or motion detector.



https://www.instructables.com/ORIG/FGM/7F11/KST8YXNU/FGM7F11KST8YXNU.stl (https://content.instructables.com/ORIG/FGM/7F11/KST8YXNU/FGM7F11KST8YXNU.stl)

View in 3D Download (https://content.instructables.com/ORIG/FGM/7F11/KST8YXNU/FGM7F11KST8YXNU.stl)

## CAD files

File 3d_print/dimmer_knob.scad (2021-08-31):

use <lib/mattwach/util.scad>
use <lib/mattwach/shapes.scad>

module dimmer_knob() {
  overlap = 0.01;

  hole_diameter = 6;
  hole_depth = 7;

  height = 9;
  diameter = 15;

  difference() {
    cylinder(d=diameter, h=height);
    tz(-overlap) rounded_cylinder(d=hole_diameter, h=hole_depth + overlap, chamfer=-1);
  }
}

$fa = 2;
$fs = 0.5;
dimmer_knob();

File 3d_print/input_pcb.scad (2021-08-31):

use <lib/mattwach/util.scad>
use <lib/mattwach/vitamins/electronics/buttons.scad>
use <lib/mattwach/vitamins/electronics/oled.scad>
use <lib/mattwach/vitamins/electronics/potentiometers.scad>

include <lib/NopSCADlib/core.scad>
include <lib/NopSCADlib/vitamins/pcbs.scad>
include <lib/NopSCADlib/vitamins/pin_headers.scad>

module input_pcb() {
  board_x_offset = 5.85;
  board_y_offset = 3.5;
  board_thickness = 1.6;
  pin_spacing = 2.54;

  function cx(x) = board_x_offset + x * pin_spacing;
  function cy(y) = board_y_offset + y * pin_spacing;

  module base_pcb() {
    txy(35, 15) pcb(PERF70x30);
  }

  module green_button() {
    translate([cx(18), cy(8), board_thickness])
      rz(-90) push_switch_12x12(button_color="#0D0");
  }

  module red_button() {
    translate([cx(18), cy(2), board_thickness])
      rz(-90) push_switch_12x12();
  }

  module oled_socket() {
    translate([cx(11.5), cy(9), board_thickness]) pin_socket(2p54header, 4, 1);
  }

  module oled_support_socket() {
    translate([cx(11.5), cy(0), board_thickness]) pin_socket(2p54header, 10, 1);
  }

  module pot() {
    translate([
        12,
        15.5,
        board_thickness
    ]) rz(-90) potentiometer_plate_mount();
  }

  module oled() {
    translate([
        21.3,
        0.1,
        12.7,
    ]) oled_128x64_i2c();
  }

  module connector() {
    translate([
        70,
        14.9,
        -0.6]) ry(90) rz(-90) jst_xh_header(jst_xh_header, 8);
  }

  base_pcb();
  green_button();
  red_button();
  oled_socket();
  oled_support_socket();
  pot();
  oled();
  connector();
}

$fa = 2;
$fs = 0.5;
input_pcb();

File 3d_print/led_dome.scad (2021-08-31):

use <lib/mattwach/util.scad>
use <lib/mattwach/vitamins/electronics/led.scad>
use <lib/mattwach/vitamins/bolts.scad>

module led_dome(led_dome_radius, shell_thickness, base_height, show_leds=true) {
  overlap = 0.01;

  led_dome_diameter = led_dome_radius * 2;

  mount_hole_offset = 9.5;

  low_angle = 20;
  high_angle = 50;
  inset = 1.5;

  module dome() {
    module led_ports() {
      module led_port() {
        wire_hole_x_angle = 60;

        module wire_hole(x_angle) {
          wire_hole_diameter = 6;
          wire_hole_offset = 13;
          tx(led_dome_radius - shell_thickness * 2)
            rx(x_angle) ry(90) hull() {
              cylinder(d=wire_hole_diameter, h=shell_thickness * 2);
              tx(wire_hole_offset) cylinder(d=wire_hole_diameter, h=shell_thickness * 2);
            }
        }

        module mount_hole(hole_offset) {
          mount_hole_diameter = 2.35;
          tz(hole_offset) tx(led_dome_radius - shell_thickness * 2) ry(90)
            cylinder(d=mount_hole_diameter, h=shell_thickness * 2);
        }

        module inset_cutout() {
          inset_cutout_diameter = 22;
          tx(led_dome_radius - inset) ry(90)
            cylinder(d=inset_cutout_diameter, h=inset + overlap);
        }

        module back_hole() {
          back_hole_diameter = 14;
          tx(led_dome_radius - shell_thickness * 2) ry(90)
            cylinder(d=back_hole_diameter, h=shell_thickness * 2);
        }

        union() {
          inset_cutout();
          back_hole();
          wire_hole(wire_hole_x_angle);
          wire_hole(-wire_hole_x_angle);
          wire_hole(180 + wire_hole_x_angle);
          wire_hole(180 - wire_hole_x_angle);
          mount_hole(mount_hole_offset);
          mount_hole(-mount_hole_offset);
        }
      }

      //ry(-low_angle) led_port();
      for (i=[0:3]) {
        rz(i * 90) ry(-low_angle) led_port();
        rz(i * 90 + 45) ry(-high_angle) led_port();
      }
      ry(-90) led_port();
    }

    difference() {
      sphere(r=led_dome_radius);
      sphere(r=led_dome_radius - shell_thickness);
      translate([
          -led_dome_radius - overlap,
          -led_dome_radius - overlap,
          -led_dome_radius - overlap]) cube([
            led_dome_diameter + overlap * 2,
            led_dome_diameter + overlap * 2,
            led_dome_radius + overlap]);
      led_ports();
    }
  }

  module base() {
    difference() {
      cylinder(r=led_dome_radius, h=base_height + overlap);
      tz(-overlap) cylinder(
          r=led_dome_radius - shell_thickness,
          h=base_height + overlap * 3);
    }
  }

  module leds() {
    module led() {
      tx(led_dome_radius - inset) rx(90) ry(90) {
        hex_led_3w();
        tz(1.3) {
          ty(mount_hole_offset) bolt_M2_5(6);
          ty(-mount_hole_offset) bolt_M2_5(6);
        }
      }
    }
    //ry(-low_angle) tx(led_dome_radius) led();
    for (i=[0:3]) {
      rz(i * 90) ry(-low_angle) led();
      rz(i * 90 + 45) ry(-high_angle) led();
    }
    ry(-90) led();
  }

  color("#eee", 0.7) union() {
    tz(base_height) dome();
    base();
  }
  if (show_leds) {
    tz(base_height) leds();
  }
}

/*
$fa = 2;
$fs = 0.5;
led_dome(true);
*/

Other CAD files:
3d_print/led_lamp.scad
3d_print/master_pcb.scad

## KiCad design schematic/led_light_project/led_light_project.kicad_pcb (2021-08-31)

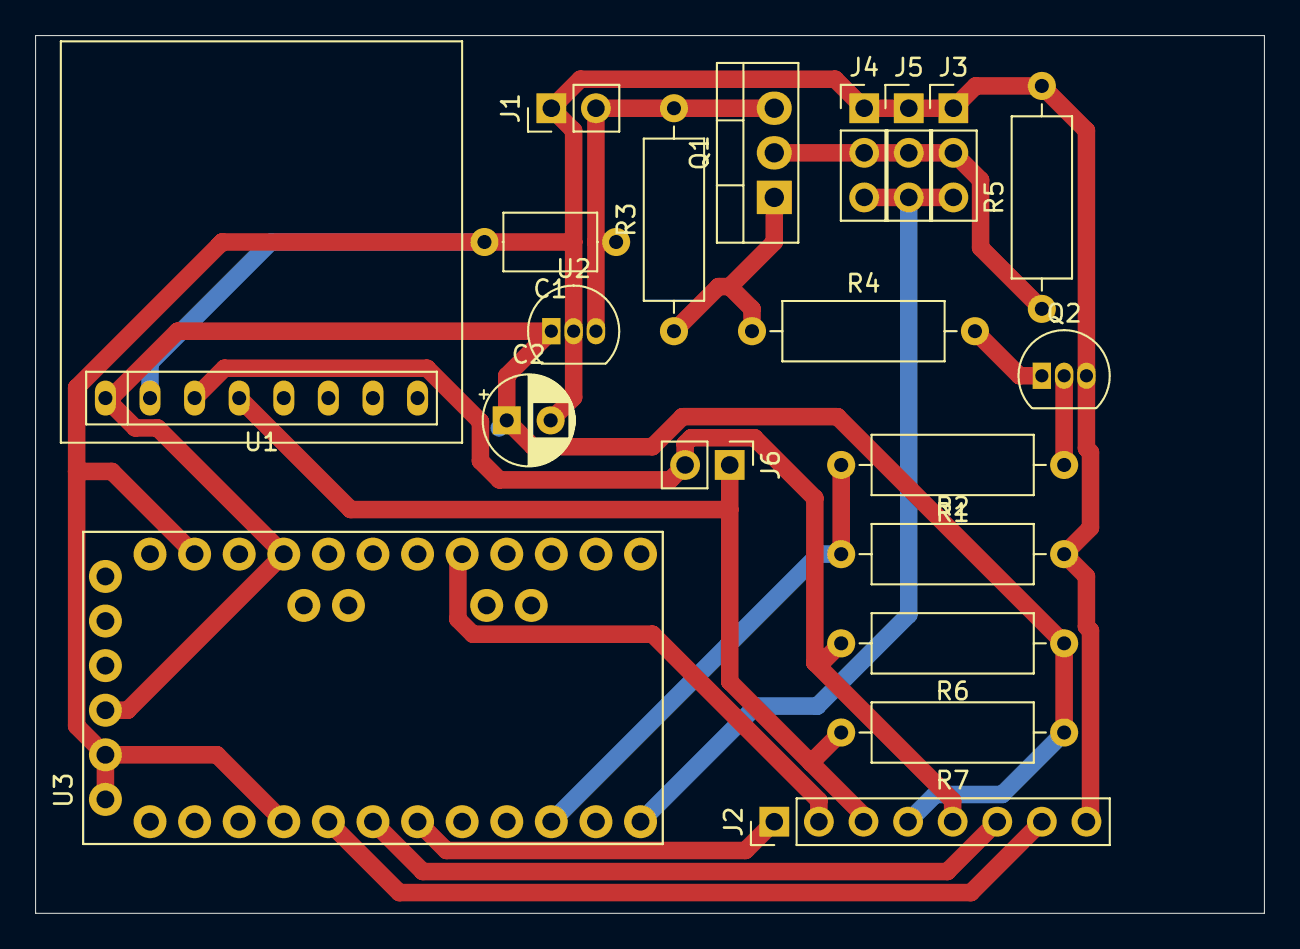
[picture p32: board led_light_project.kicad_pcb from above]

Board: 2 copper layers, 70.0 x 50.0 mm, 20 parts (0 on the bottom side), 15 nets.

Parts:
C1: 100n; C_Axial_L5.1mm_D3.1mm_P7.50mm_Horizontal
C2: 10u; CP_Radial_D5.0mm_P2.50mm
J1: PWR_IN; PinHeader_1x02_P2.54mm_Vertical
J2: control_board_conn; PinHeader_1x08_P2.54mm_Vertical
J3: PICO_BUCK1; PinHeader_1x03_P2.54mm_Vertical
J4: PICO_BUCK2; PinHeader_1x03_P2.54mm_Vertical
J5: PICO_BUCK3; PinHeader_1x03_P2.54mm_Vertical
J6: I2C_Hookup; PinHeader_1x02_P2.54mm_Vertical
Q1: FQP27P06; TO-220-3_Vertical
Q2: BS170; TO-92_Inline
R1: 1k; R_Axial_DIN0309_L9.0mm_D3.2mm_P12.70mm_Horizontal
R2, R3, R5: 47k; R_Axial_DIN0309_L9.0mm_D3.2mm_P12.70mm_Horizontal
R4: 10k; R_Axial_DIN0309_L9.0mm_D3.2mm_P12.70mm_Horizontal
R6, R7: 4.7k; R_Axial_DIN0309_L9.0mm_D3.2mm_P12.70mm_Horizontal
U1: INA260; Adadruit_INA260_Breakout_Board
U2: LM2936-3.3_TO92; TO-92_Inline
U3: ARDUINO_PRO_MINI; MODULE_ARDUINO_PRO_MINI

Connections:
+3V3: C2.1, J2.4, R6.1, R7.1, U1.10, U2.1, U3.JP1_4, U3.JP6_4
+28V: C1.1, J1.2, Q1.3, R3.2, U2.3
/GREEN_BUT: J2.6, U3.JP7_7
/LED_ON: R1.2, R2.1, U3.JP7_3
/LED_VCC: J3.2, J4.2, J5.2, Q1.2, R5.1
/POTIN: J2.2, U3.JP6_8
/POT_VCC: J2.1, U3.JP7_6
/PWM: J3.3, J4.3, J5.3, U3.JP7_1
/RED_BUT: J2.7, U3.JP7_8
/SCL: J2.5, J6.2, R6.2, U1.9
/SDA: J2.3, J6.1, R7.2, U1.8
GND: C1.2, C2.2, J1.1, J2.8, J3.1, J4.1, J5.1, Q2.3, R2.2, R5.2, U1.6, U2.2, U3.JP1_5, U3.JP1_6, U3.JP6_2, U3.JP7_9
unnamed: Q1.1, R3.1, R4.1
unnamed: Q2.1, R4.2
unnamed: Q2.2, R1.1

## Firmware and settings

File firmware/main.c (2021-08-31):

// LED Lamp Project
// By: Matt Wachowski
//
// Designed for Atmega328p processor.

// General libs
#include <util/delay.h>

// String conversion
#include <pstr/pstr.h>

// INA260 power meter
#include <ina260/ina260.h>

// Needed for OLED display
#include <oledm/oledm.h>
#include <oledm/ssd1306_init.h>
#include <oledm/text.h>
#include <oledm/font/terminus8x16.h>

// Enter low power mode
#include <lowpower/lowpower.h>

// project-specific libraries
#include "awake_time.h"
#include "battery_confirm_dialog.h"
#include "battery_setup_ui.h"
#include "debug.h"
#include "eeprom_settings.h"
#include "fatal.h"
#include "input.h"
#include "led_control.h"
#include "status_display.h"

//
// I/O Connections:
//
// Also see:
//  input.c
//  led_control.c
//  fatal.c
//

//  A4 - I2C SDA connection for OLED / INA260 comms
//  A5 - I2C SCL connection for OLED / INA260 comms

//
// Other Settings
//

// How long to idle before turning off the display
#define STATUS_SHOW_TIME_MS 30000  

// How long to wait before entering low power mode
#define LOW_POWER_HOLDOFF_MS 500

// Add a deadzone to the current PWM value so that it's stable
#define PWM_DEADZONE 2

// Flags that determine what to power on and off
#define POWER_LED     0x01
#define POWER_DISPLAY 0x02
#define POWER_INPUT   0x04
#define POWER_INA260  0x08

// The address depends on the A0, A1 settings on the chip.  0x40
// is typical.
#define INA260_I2C_ADDRESS 0x40

// how long to stay in fast capture mode before turning to slow capture mode
#define INA260_FAST_SAMPLE_MS 250

//
// Global Data
//

// State of 128x64 OLED display
struct OLEDM display_g;
// Tracks current state of text (cursor position) on the OLED.
struct Text text_g;
// Tracks min/max range of the dimmer
struct DimmerConfig dimmer_config_g;
// Tracks current batery voltage
uint16_t battery_mv_g;
// The type of battery in use
uint8_t battery_type_g;
// minimum voltage of current battery
uint16_t battery_min_mv_g;
// number of battery cells (0 if custom)
uint8_t battery_cell_count_g;
// true if the battery was confirmed
bool_t battery_was_confirmed_g;
// sets the time when ina260 sampling show be changed from fast to slow
// if zero, then we are already at slow capture
uint32_t slow_sample_time_trigger_ms_g;

typedef enum states {
  STATE_ALL_OFF         = 0x00 |         0 |             0 |           0 |            0,
  STATE_BATTERY_CONFIRM = 0x10 |         0 | POWER_DISPLAY | POWER_INPUT | POWER_INA260,
  STATE_BATTERY_SETUP   = 0x20 |         0 | POWER_DISPLAY | POWER_INPUT | POWER_INA260,
  STATE_STATUS_ONLY     = 0x30 |         0 | POWER_DISPLAY | POWER_INPUT | POWER_INA260,
  STATE_LED_ONLY        = 0x40 | POWER_LED |             0 | POWER_INPUT | POWER_INA260,
  STATE_LED_WITH_STATUS = 0x50 | POWER_LED | POWER_DISPLAY | POWER_INPUT | POWER_INA260,
} states;

// Current state of lamp
states state_g;
// The last time the display was updated or a bottun/pot was used.
// note this setting is also used to keep lowpower mode awake for a bit
// so that the buttons can debounce.
uint32_t start_status_show_time_ms_g;
// last read PWM value.  Needed to support PWM_DEADZONE
uint8_t current_pwm_g;

// Coordinates communication with the INA260 current/voltage monitor
struct INA260 ina260_g;

//
// Implementation
//

// Asserts I2C device status.
static void check_i2c_errors(void) {
  if (display_g.error) {
    // The display update probably wont work...
    fatal(&text_g, "DISPLAY", u8_to_pshex(display_g.error));
  }
  if (ina260_g.error) {
    fatal(&text_g, "INA260", u8_to_pshex(ina260_g.error));
  }
}

// Sets the INA260 for either fast or slow sampling
static void config_ina260(bool_t fast_sample) {
  if (fast_sample) {
    ina260_write_configuration(
        &ina260_g,
        ina260_create_configuration(
          AVG_4_SAMPLES,
          CONVERSION_TIME_8244_US,
          CONVERSION_TIME_8244_US,
          OPERATING_MODE_CONTINUOUS_CURRENT_AND_VOLTAGE));
  } else {
    ina260_write_configuration(
        &ina260_g,
        ina260_create_configuration(
          AVG_128_SAMPLES,
          CONVERSION_TIME_8244_US,
          CONVERSION_TIME_8244_US,
          OPERATING_MODE_CONTINUOUS_CURRENT_AND_VOLTAGE));
  }
}

static bool_t update_led_brightness(bool_t use_deadzone) {
  uint8_t pwm = get_dimmer_value(&dimmer_config_g);
  if (pwm == current_pwm_g) {
    return FALSE;  // no change
  }

  // only apply deadzone if not at ends, otherwise we might not be able
  // to reach min and max due to deadzone overlapping them.
  if (use_deadzone &&
      pwm > dimmer_config_g.min_pwm &&
      pwm < dimmer_config_g.max_pwm) {
    if (pwm > current_pwm_g && (pwm - current_pwm_g) <= PWM_DEADZONE) {
      return FALSE;  // not enough change
    }
    if (pwm < current_pwm_g && (current_pwm_g - pwm) <= PWM_DEADZONE) {
      return FALSE;  // not enough change
    }
  }

  // enough of a change
  current_pwm_g = pwm;
  led_set_pwm(current_pwm_g);
  // reset show timer
  start_status_show_time_ms_g = awake_time_in_ms();

  // setup temporary fast sampling for better UI responsiveness
  if (!slow_sample_time_trigger_ms_g) {
    config_ina260(TRUE);
  }
  slow_sample_time_trigger_ms_g = start_status_show_time_ms_g + INA260_FAST_SAMPLE_MS;

  return TRUE;
}

static void change_state(states new_state) {
  DEBUG_STR("Chaange State: ");
  DEBUG_PSTRLN(u8_to_pshex(new_state));
  if ((new_state & POWER_LED) && !(state_g & POWER_LED)) {
    update_led_brightness(FALSE);
    led_power_on(current_pwm_g);
  } else if (!(new_state & POWER_LED) && (state_g & POWER_LED)) {
    led_power_off(current_pwm_g);
  }

  if ((new_state & POWER_INA260) && !(state_g & POWER_INA260)) {
    ina260_set_operating_mode(
        &ina260_g,
        OPERATING_MODE_CONTINUOUS_CURRENT_AND_VOLTAGE); 
  } else if (!(new_state & POWER_INA260) && (state_g & POWER_INA260)) {
    ina260_set_operating_mode(&ina260_g, OPERATING_MODE_POWER_DOWN2); 
  }

  if ((new_state & POWER_INPUT) && !(state_g & POWER_INPUT)) {
    input_wake();
  } else if (!(new_state & POWER_INPUT) && (state_g & POWER_INPUT)) {
    input_sleep();
  }

  if ((new_state & POWER_DISPLAY) && !(state_g & POWER_DISPLAY)) {
    oledm_display_on(&display_g);
  } else if (!(new_state & POWER_DISPLAY) && (state_g & POWER_DISPLAY)) {
    oledm_display_off(&display_g);
  }
  
  status_display_init();
  // Note: before changing this line, consider that the
  // variable is also used to track when to enter low power mode
  // in loop()
  start_status_show_time_ms_g = awake_time_in_ms();
  state_g = new_state;
}

// Enter battery confirmation menu
static void confirm_battery() {
  // This is called so that we are sure that the ina260 is powered up
  // for a reading.
  change_state(STATE_BATTERY_CONFIRM);
  battery_mv_g = ina260_read_voltage_in_mv(&ina260_g);
  struct EEPROMSettings* settings = eeprom_settings();
  battery_type_g = settings->battery_type;
  battery_cell_count_g = determine_battery_cell_count(battery_type_g, battery_mv_g);
  if (battery_type_g == BATTERY_TYPE_CUSTOM) {
    battery_min_mv_g = settings->custom_battery_min_mv;
  } else if (battery_cell_count_g > 0) {
    battery_min_mv_g =
      determine_min_battery_mv(battery_type_g, battery_cell_count_g);
  } else {
    battery_min_mv_g = 0;
  }

  if (battery_min_mv_g == 0) {
    battery_setup_init();
    change_state(STATE_BATTERY_SETUP);
  }
}

// Initialize hardware and ports
static void init(void) {
  awake_time_init();

  oledm_basic_init(&display_g);
  oledm_start(&display_g);
  oledm_clear(&display_g, 0x00);
  text_init(&text_g, terminus8x16, &display_g);
  DEBUG_STRLN("OLED Initialized");

  ina260_init(&ina260_g, INA260_I2C_ADDRESS);
  config_ina260(TRUE);
  slow_sample_time_trigger_ms_g = awake_time_in_ms() + INA260_FAST_SAMPLE_MS;
  DEBUG_STRLN("INA260 Initialized");
  check_i2c_errors();

  dimmer_config_g.min_pwm = 3;  // ~1%
  dimmer_config_g.max_pwm = 255;  // 100%
  input_init();
  DEBUG_STRLN("INPUT Initialized");

  battery_was_confirmed_g = FALSE;
  confirm_battery();
}


// Returns true iff it's time to turn off the display due to inactivity
static inline bool_t status_time_is_expired(void) {
  return (start_status_show_time_ms_g + STATUS_SHOW_TIME_MS) < awake_time_in_ms();
}

// Updates the OLED with current status
static void update_status(void) {
  status_display_render(
      &text_g,
      battery_mv_g,
      ina260_read_current_in_ma(&ina260_g),
      battery_min_mv_g,
      battery_type_g,
      battery_cell_count_g
  );
}

// STATE_ALL_OFF: Nothing is on, use as little power as possible.
static void state_all_off(bool_t red_pressed, bool_t green_pressed) {
  // Assume this is only called if one of the two buttons was pressed...
  if (!battery_was_confirmed_g) {
    confirm_battery();
  } else if (green_pressed) {
    change_state(STATE_LED_WITH_STATUS);
  } else if (red_pressed) {
    change_state(STATE_STATUS_ONLY);
  }
}

// STATE_BATTERY_CONFIRM
static void state_battery_confirm(bool_t red_pressed, bool_t green_pressed) {
  display_battery_confirm_dialog(
      &text_g,
      battery_mv_g,
      battery_type_g,
      battery_min_mv_g,
      battery_cell_count_g);
  if (green_pressed) {
    oledm_clear(&display_g, 0);
    battery_was_confirmed_g = TRUE;
    if (battery_mv_g > battery_min_mv_g) {
      change_state(STATE_LED_WITH_STATUS);
    } else {
      change_state(STATE_STATUS_ONLY);
    }
  } else if (red_pressed) {
    oledm_clear(&display_g, 0);
    battery_setup_init();
    change_state(STATE_BATTERY_SETUP);
  } else if (status_time_is_expired()) {
    change_state(STATE_ALL_OFF);
  }
}

static void state_battery_setup(bool_t red_pressed, bool_t green_pressed) {
  if (battery_setup_ui(&text_g, red_pressed, green_pressed, battery_mv_g)) {
    confirm_battery();
  } else if (status_time_is_expired()) {
    change_state(STATE_ALL_OFF);
  }
}

// STATE_STATUS_ONLY:
static void state_status_only(bool_t red_pressed, bool_t green_pressed) {
  update_status();

  if (green_pressed && (battery_mv_g >= battery_min_mv_g)) {
    change_state(STATE_LED_WITH_STATUS);
  } else if (red_pressed || status_time_is_expired()) {
    change_state(STATE_ALL_OFF);
  }
}

static void state_led_only(bool_t red_pressed, bool_t green_pressed) {
  const bool_t brightness_was_changed = update_led_brightness(TRUE);
  if (battery_mv_g < battery_min_mv_g) {
    change_state(STATE_STATUS_ONLY);
  } else if (green_pressed || brightness_was_changed) {
    change_state(STATE_LED_WITH_STATUS);
  } else if (red_pressed) {
    change_state(STATE_ALL_OFF);
  }
}

static void state_led_with_status(bool_t red_pressed, bool_t green_pressed) {
  update_led_brightness(TRUE);
  update_status();
  if (battery_mv_g < battery_min_mv_g) {
    change_state(STATE_STATUS_ONLY);
  } else if (green_pressed) {
    change_state(STATE_LED_ONLY);
  } else if (red_pressed) {
    change_state(STATE_ALL_OFF);
  }
}

static void loop(void) {
  check_i2c_errors();

  if (state_g & POWER_INA260) {
    if ((slow_sample_time_trigger_ms_g > 0) &&
        (awake_time_in_ms() > slow_sample_time_trigger_ms_g)) {
      // slow sampling for better reading stability
      config_ina260(FALSE); 
      slow_sample_time_trigger_ms_g = 0;
    }

    battery_mv_g = ina260_read_voltage_in_mv(&ina260_g);
  }

  const bool_t red_pressed = red_button_was_pressed();
  const bool_t green_pressed = green_button_was_pressed();

  if (red_pressed || green_pressed) {
    start_status_show_time_ms_g = awake_time_in_ms();
  }

  switch (state_g) {
    case STATE_ALL_OFF:
      state_all_off(red_pressed, green_pressed);
      break;
    case STATE_BATTERY_CONFIRM:
      state_battery_confirm(red_pressed, green_pressed);
      break;
    case STATE_BATTERY_SETUP:
      state_battery_setup(red_pressed, green_pressed);
      break;
    case STATE_STATUS_ONLY:
      state_status_only(red_pressed, green_pressed);
      break;
    case STATE_LED_ONLY:
      state_led_only(red_pressed, green_pressed);
      break;
    case STATE_LED_WITH_STATUS:
      state_led_with_status(red_pressed, green_pressed);
      break;
  }
}

void main(void) {
  DEBUG_INIT();
  init();
  while (1) {
    loop();
    if (state_g == STATE_ALL_OFF &&
        (awake_time_in_ms() > (start_status_show_time_ms_g + LOW_POWER_HOLDOFF_MS))) {
      // Waiting for keypresses
      DEBUG_STRLN("Power Down");
      lowpower_powerDown(SLEEP_FOREVER, ADC_OFF, BOD_OFF);
    } else {
      DEBUG_STRLN("Power Idle");
      _delay_ms(30);
      /*  This is causing erratic behavior after working for a while
          - Seems ok on a breadboard
          - Seems ok when I add various delays around the command, but I don't know why
            and it's not stable across other changes.
          - Tried turning more stuff below "on" but it didn't seem to help.
      lowpower_idle(
          SLEEP_30MS,
          ADC_ON,
          TIMER2_OFF,
          TIMER1_ON,
          TIMER0_ON,
          SPI_OFF,
          USART0_ON,
          TWI_ON
      );
      */
    }
  }
}

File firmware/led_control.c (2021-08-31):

#include "led_control.h"
#include <util/delay.h>

#include <avr/io.h>

// PD7 (D7) - LED power.  Set high for ON.  Set low (pr preferably Hi-Z)
// for OFF.
#define LED_POWER_PORT PORTD
#define LED_POWER_DDR DDRD
#define LED_POWER_PIN 7

// LED PWM signal is fixed at PB1 (D9, OC1A)

#define MAX_TIMER_VALUE ((uint32_t)F_CPU / 400)  // Updates will be around 400Hz
#define FET_POWER_TIME_MS 2  // give the FET a little time to turn on and off completly

// how fast to turn on and off
#define PWM_STEP 3

void led_power_on(uint8_t pwm) {
  //
  // PWM Setup
  //
  DDRB |= (1 << 1);  // Set PB1 (PWM) as an output
  OCR1A = 0;
  TCCR1A = 0x82;  // COM1A1 - Clear OC1A on compare match
                  // WGM11 - PWM mode with ICR1 as top
  TCCR1B = 0x19;  // WGM13, WGM12 - PWM Mode with ICR1 on top
                  // CS10 - Full speed for now
  ICR1 = MAX_TIMER_VALUE;  // maximum count value (1023?)

  // Turn on PFET
  LED_POWER_DDR |= (1 << LED_POWER_PIN);
  LED_POWER_PORT |= (1 << LED_POWER_PIN);
  _delay_ms(FET_POWER_TIME_MS);

  // work toward full brightness
  for (uint8_t pwmi = 0; pwmi < pwm; pwmi += PWM_STEP) {
    led_set_pwm(pwmi);
    _delay_ms(1);
  }
  led_set_pwm(pwm);
}

void led_power_off(uint8_t start_pwm) {
  // work toward min brightness
  for (int16_t pwmi = start_pwm; pwmi > 0; pwmi -= PWM_STEP) {
    led_set_pwm((uint8_t)pwmi);
    _delay_ms(1);
  }
  led_set_pwm(0);

  // Turn off FET (Hi-Z)
  LED_POWER_DDR &= ~(1 << LED_POWER_PIN);
  LED_POWER_PORT &= ~(1 << LED_POWER_PIN);
  _delay_ms(FET_POWER_TIME_MS);

  // Turn off PWM
  TCCR1B = 0x18; // timer is stopped
  DDRB &= ~(1 << 1);  // Set PB1 (PWM) as an input
}

void led_set_pwm(uint8_t pwm) {
  OCR1A = (uint16_t)((uint32_t)pwm * MAX_TIMER_VALUE / 255);
}
